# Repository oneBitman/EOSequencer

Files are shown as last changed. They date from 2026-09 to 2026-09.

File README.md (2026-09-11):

# EOSequencer

**EOSequencer** is an open-source hardware MIDI step sequencer firmware for Arduino and compatible microcontrollers. It is built as an enhanced fork of the classic **Beat707NXT** engine by William Kalfelz, featuring updated workflow options, refined timing stability, and customized interface controls.

🌐 **Website (buy a kit):** [https://dsmcz.com/prestashop/en/home/23957-eoseq-full-kit-with-eu-psu-yellow-purple-enclousure-v10-may-2026.html](https://dsmcz.com/prestashop/en/home/23957-eoseq-full-kit-with-eu-psu-yellow-purple-enclousure-v10-may-2026.html)

---

## Features

- **Multi-track Step Sequencing:** Intuitive step entry for rhythm and melodic tracks.
- **Hardware Integration:** Direct support for MIDI In/Out, TM1638 led & key board based interface.
- **Enhanced Engine:** Modifications built over Beat707NXT for improved stability and workflow options.
- **Arduino Compatible:** Designed to compile cleanly using the standard Arduino IDE.

---

## Hardware Requirements

To build and run EOSequencer, you will need:

1. **Microcontroller Board:**
   - Only for Arduino Pro Mini 328P, 3.3V, 8Mhz
   - Eosequencer was developed for ATmega328P but code will run flawless on 328PB variant
2. **User Interface Components:**
   - 3x TM1638 board
3. **MIDI Hardware Interface:**
   - Standard DIN-5 or TRS MIDI input and output circuits (optocoupler-driven MIDI IN, standard MIDI OUT driver).

---

## Software & Build Setup

### Option A: Using Arduino IDE

1. **Download & Install Arduino IDE** (v1.8.x or v2.x).
2. **Clone the Repository:**
   ```bash
   git clone https://github.com/oneBitman/EOSequencer.git
   ```
3. **Install Required Libraries:**
   Ensure the following libraries are installed in your Arduino library manager:
   - `MIDI` (by Francois Best)
   - `Wire` & `SPI` (Built-in)
4. **Open Project:**
   Open `EOSequencer.ino` inside the `EOSequencer/` folder.
5. **Compile & Upload:**
   You MUST install MiniCore board library for gaining more programming space, code exceeds 30720 bytes!
   Recommended bootloader (512 bytes): Optiboot/Urboot --- urboot_m328p_1s_autobaud_uart0_rxd0_txd1_led+b5_ee_ce_hw_stk500

   How to install MiniCore board library (Arduino IDE 2.x on Windows 11)

   File → Preferences → Additional Boards Manager URLs
   1.) → paste: https://mcudude.github.io/MiniCore/package_MCUdude_MiniCore_index.json
   2.) Tools → Board → Boards Manager… → search MiniCore → Install.
   Choose Tools > Board > MiniCore > Atmega328
    Select your target board and port under **Tools**, then click **Upload**.

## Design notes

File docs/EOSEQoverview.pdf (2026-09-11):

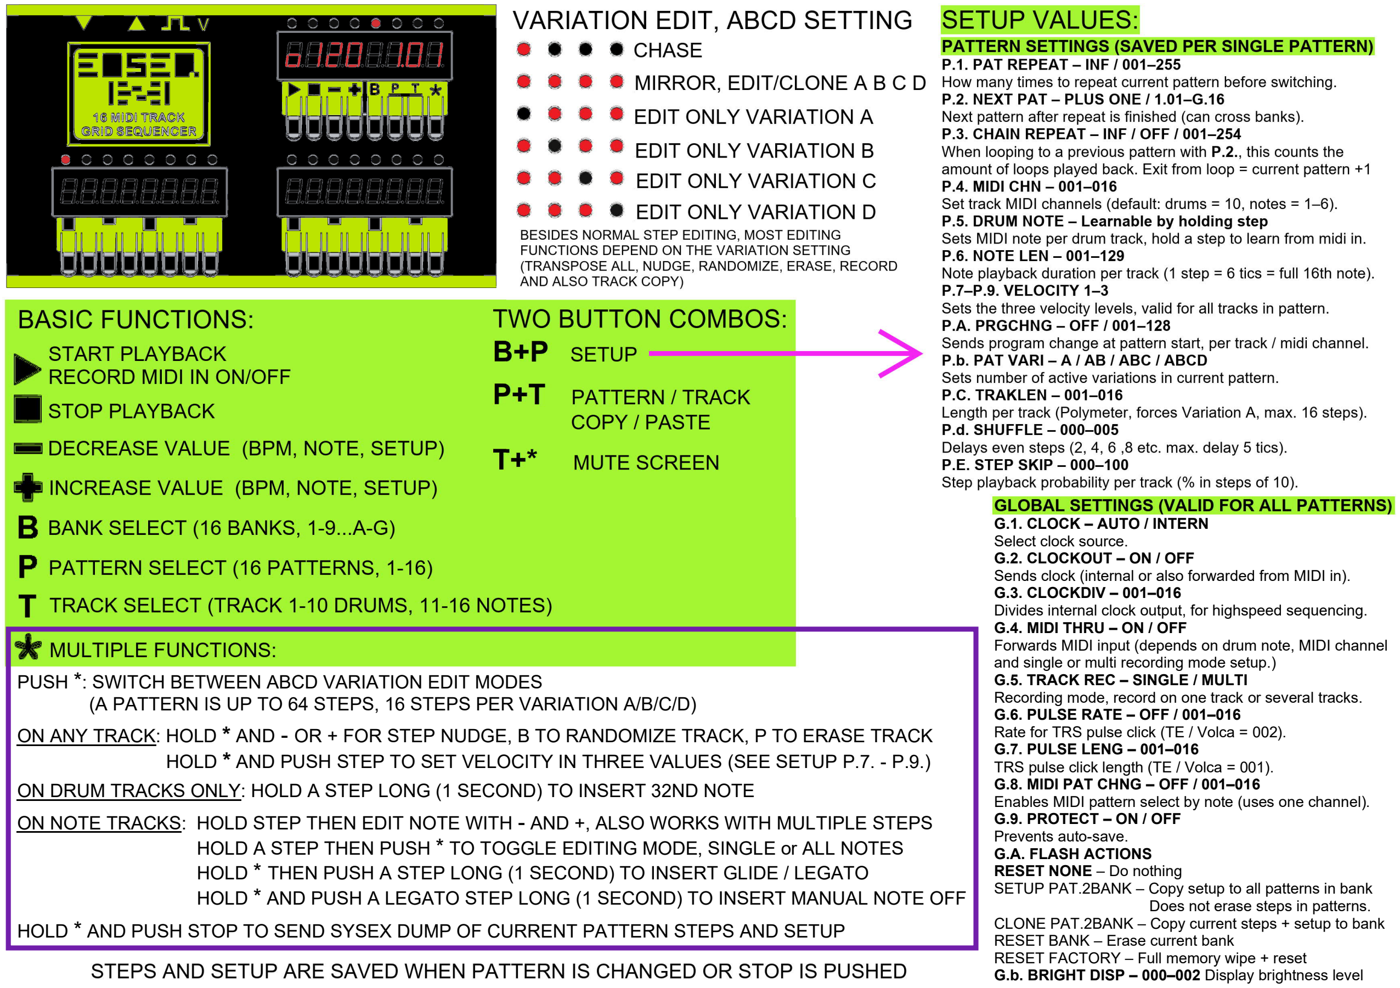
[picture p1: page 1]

PUSH *: SWITCH BETWEEN ABCD VARIATION EDIT MODES (A PATTERN IS UP TO 64 STEPS, 16 STEPS PER VARIATION A/B/C/D) ON ANY TRACK: HOLD * AND - OR + FOR STEP NUDGE, B TO RANDOMIZE TRACK, P TO ERASE TRACK HOLD * AND PUSH STEP TO SET VELOCITY IN THREE VALUES (SEE SETUP P.7. - P.9.) ON DRUM TRACKS ONLY: HOLD A STEP LONG (1 SECOND) TO INSERT 32ND NOTE ON NOTE TRACKS: HOLD STEP THEN EDIT NOTE WITH - AND +, ALSO WORKS WITH MULTIPLE STEPS HOLD A STEP THEN PUSH * TO TOGGLE EDITING MODE, SINGLE or ALL NOTES HOLD * THEN PUSH A STEP LONG (1 SECOND) TO INSERT GLIDE / LEGATO HOLD * AND PUSH A LEGATO STEP LONG (1 SECOND) TO INSERT MANUAL NOTE OFF HOLD * AND PUSH STOP TO SEND SYSEX DUMP OF CURRENT PATTERN STEPS AND SETUP

# TWO BUTTON COMBOS:

## B+P SETUP

## P+T PATTERN / TRACK COPY / PASTE T+* MUTE SCREEN

GLOBAL SETTINGS (VALID FOR ALL PATTERNS) G.1. CLOCK – AUTO / INTERN
Select clock source.
G.2. CLOCKOUT – ON / OFF
Sends clock (internal or also forwarded from MIDI in). G.3. CLOCKDIV – 001–016
Divides internal clock output, for highspeed sequencing. G.4. MIDI THRU – ON / OFF
Forwards MIDI input (depends on drum note, MIDI channel and single or multi recording mode setup.)
G.5. TRACK REC – SINGLE / MULTI
Recording mode, record on one track or several tracks. G.6. PULSE RATE – OFF / 001–016
Rate for TRS pulse click (TE / Volca = 002).
G.7. PULSE LENG – 001–016
TRS pulse click length (TE / Volca = 001).
G.8. MIDI PAT CHNG – OFF / 001–016
Enables MIDI pattern select by note (uses one channel). G.9. PROTECT – ON / OFF
Prevents auto-save.
G.A. FLASH ACTIONS
RESET NONE – Do nothing
SETUP PAT.2BANK – Copy setup to all patterns in bank Does not erase steps in patterns. CLONE PAT.2BANK – Copy current steps + setup to bank RESET BANK – Erase current bank
RESET FACTORY – Full memory wipe + reset
G.b. BRIGHT DISP – 000–002 Display brightness level

# BASIC FUNCTIONS:

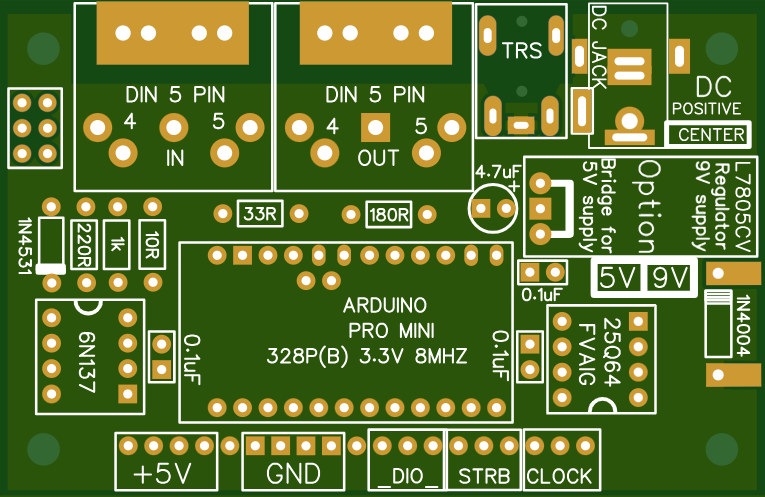
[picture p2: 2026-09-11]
hardware/gerber-export-1789131451506.png

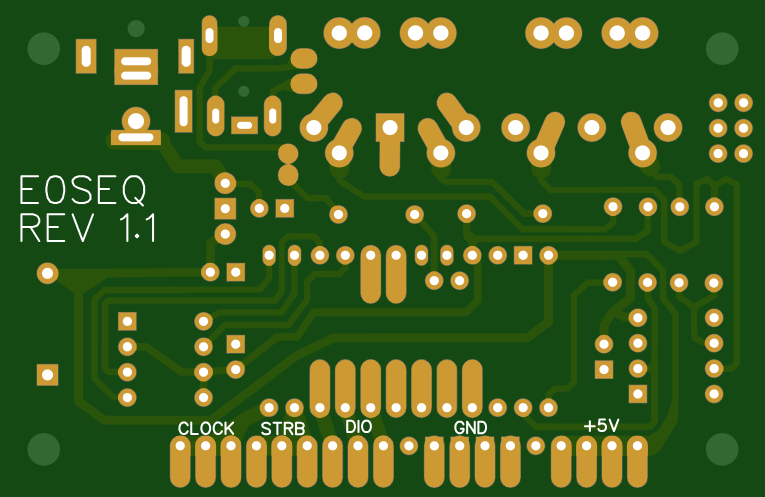
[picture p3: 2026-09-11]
hardware/gerber-export-1789131424221.png

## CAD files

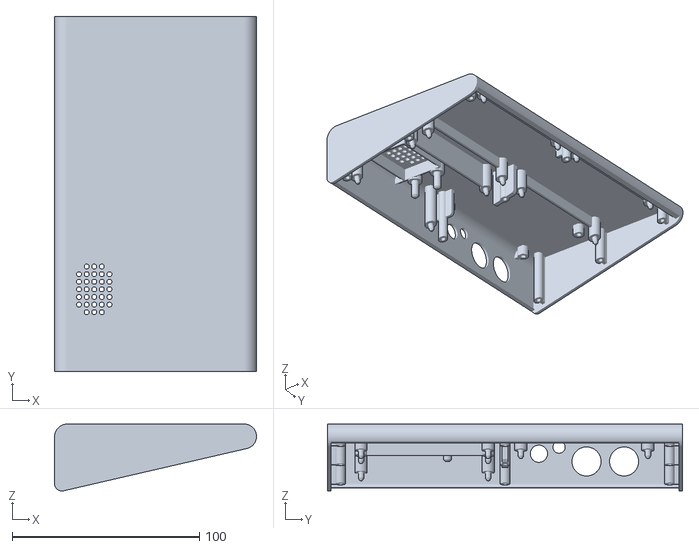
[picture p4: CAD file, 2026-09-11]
hardware/enclosure/wp5_Base.STL
108.0 x 189.7 x 35.8

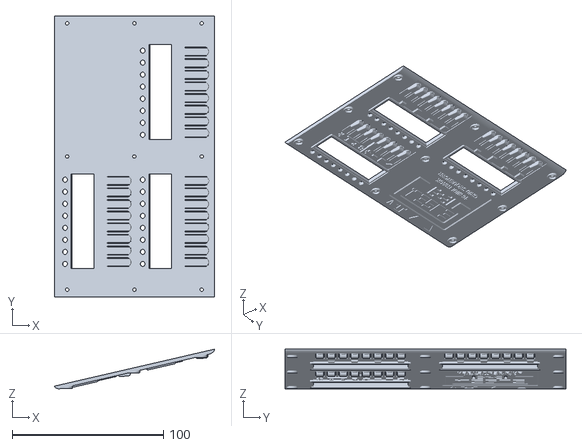
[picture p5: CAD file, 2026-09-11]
hardware/enclosure/wp6_Top.STL
106.0 x 185.7 x 26.2

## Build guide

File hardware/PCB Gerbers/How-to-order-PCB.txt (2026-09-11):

How to Order PCB

Please refer to:
https://docs.easyeda.com/en/PCB/Order-PCB

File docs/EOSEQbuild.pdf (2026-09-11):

# *** EOSEQUENCER ***

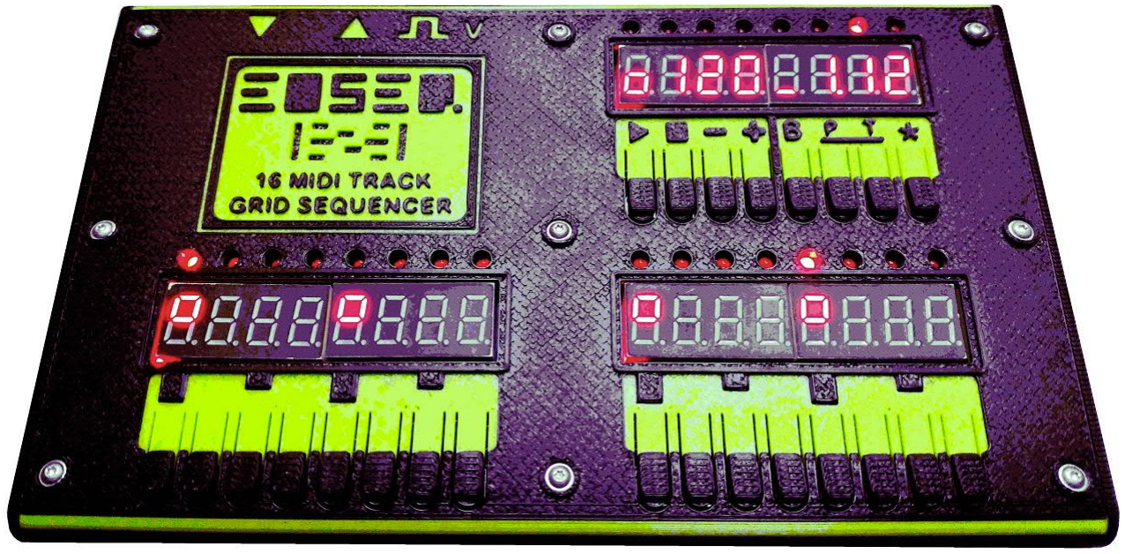
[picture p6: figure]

# DIY BUILD MANUAL PCB VERSION 1 . 1

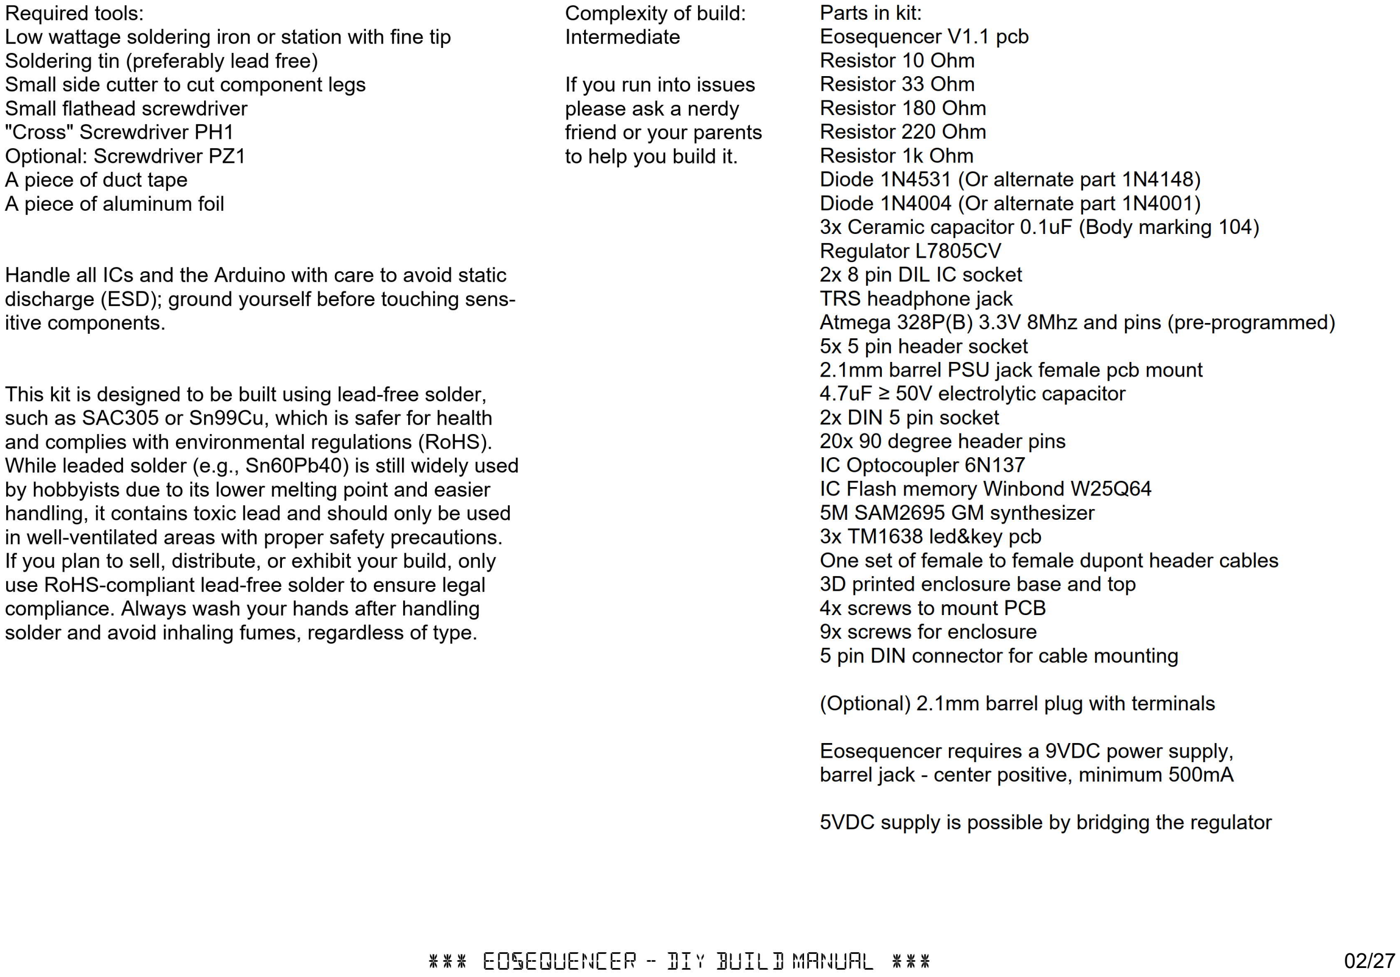
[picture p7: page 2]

Parts in kit:
Eosequencer V1.1 pcb
Resistor 10 Ohm
Resistor 33 Ohm
Resistor 180 Ohm
Resistor 220 Ohm
Resistor 1k Ohm
Diode 1N4531 (Or alternate part 1N4148) Diode 1N4004 (Or alternate part 1N4001)
3x Ceramic capacitor 0.1uF (Body marking 104) Regulator L7805CV
2x 8 pin DIL IC socket
TRS headphone jack
Atmega 328P(B) 3.3V 8Mhz and pins (pre-programmed) 5x 5 pin header socket
2.1mm barrel PSU jack female pcb mount
4.7uF 50V electrolytic capacitor
2x DIN 5 pin socket
20x 90 degree header pins
IC Optocoupler 6N137
IC Flash memory Winbond W25Q64
5M SAM2695 GM synthesizer
3x TM1638 led&key pcb
One set of female to female dupont header cables 3D printed enclosure base and top
4x screws to mount PCB
9x screws for enclosure
5 pin DIN connector for cable mounting

(Optional) 2.1mm barrel plug with terminals

Eosequencer requires a 9VDC power supply, barrel jack - center positive, minimum 500mA

5VDC supply is possible by bridging the regulator

Find resistor 10 Ohm
Brown Black Black Gold
Bend legs | Put resistor in place
Solder in place | Trim legs

Find resistor 33 Ohm
Orange Orange Black Gold
Bend legs | Put resistor in place
Solder in place | Trim legs

Find resistor 180 Ohm
Brown Gray Brown Gold
Bend legs | Put resistor in place
Solder in place | Trim legs

Find resistor 220 Ohm
Red Red Brown Gold
Bend legs | Put resistor in place
Solder in place | Trim legs

Find resistor 1k Ohm
Brown Black Red Gold
Bend legs | Put resistor in place
Solder in place | Trim legs

Find diode 1N4531
Red body colour
Alternate part: 1N4148
Bend legs | Put diode in place, observe correct orientation as indicated on pcb
Solder in place | Trim legs

Find diode 1N4004
Black body colour
Alternate part: 1N4001
Bend legs | Put diode in place, observe correct orientation as indicated on pcb
Solder in place | Trim legs

Find 3x capacitor 0.1uF
Body marking 104
Put capacitors into place | Solder in place

Trim legs

Find voltage regulator L7805CV Bend legs as shown

Put regulator into place
Regulator should be mounted with distance from pcb, it can slightly heat up and we do not want heat to spread to other components

Solder regulator pins

Alternative version for 5VDC supply: Instead of regulator solder a bridge in place (Use leftovers from component legs)

Solder bridge in place

Find 2x 8 pin IC sockets | Put sockets into place, mind orientation notch as in- dicated on pcb

Optionally bend two pins of each socket so they don't fall out

Solder both sockets into place | Finished socket left | Finished socket right

Find TRS headphone jack | Put headphone jack into place | Solder headphone jack in place

Finished headphone socket

Find arduino and pins in bag | Divide pins as shown, keep 90° pins in bag for later | Put pins into pcb as shown, short end on top, mind the gap - We are using pcb as a holder to mount the pins to arduino.
Put arduino onto pins | Solder all pins, only on arduino, not on bottom of pcb | Finished arduino with pins, remove arduino from pcb

Find 5x 5pin header sockets | Mount 4x 5pin header sockets as shown | Cut the remaining header socket in the middle to cre- ate a 2pin header socket. If you don't have a proper side cutter, cut the plastic on both sides with a knife and break it apart.
Mount 2pin header socket to arduino | Place arduino with header sockets into pcb | Solder all header socket pins

Find remaining 90° pins from arduino bag | Put pins into place | Solder pins in place
Finished 90° pins | Bend capacitor under pins towards pcb, slightly bend 90° pins upwards not to conflict with later mounted IC

Find PSU socket | Put PSU socket into place | Solder socket in place Alternate part might have different pins

Finished PSU socket

Find capacitor 4.7uF 50V | Put capacitor into place, mind orientation: Line on cap further away from regulator
Put capacitor into place,
orientation check: Shorter leg of cap is further away from regulator
Solder cap in place | Trim legs

Find 2x DIN 5 pin socker | Put sockets into place | Solder sockets in place
Finished DIN sockets | Optional for more stability: Solder grounding tab to pcb

Finished stability improvement

Find 19x 90° pins | Put 90° pins into place | Solder 90° pins in place

Optional: Header wiring can be soldered directly to pcb bottom without any pins

Find IC's 6N137 and W25Q64
Mount IC's into sockets, mind orientation 6N137 might have a dot instead a notch, dot = notch side

Bend arduino 90° pins if not done yet, mount arduino Pcb fully assembled

Find M5 SAM2695 midi synthesizer, cut off header cable approximately in half

Cut off the white wire, strip and tin the yellow, red and black wire ends

Put M5 SAM2695 into place on plastic pins | Optional: Melt down the pins to mount M5 SAM2695 Hint: Use a piece of aluminum foil for melting down to keep the soldering tip clean If pins are not melt down the M5 SAM2695 might slightly rattle inside the enclosure when moved M5 SAM2695 mounting done
Solder yellow wire to shown pin on midi out | Solder red and black wire to pads at black diode | Route wires as shown M5 SAM2695 installation done

Find 4x B3X6 screws and mount circuit board with PH1 screwdriver (No need to use PZ1 screwdriver)

Find 3x TM1638 led&key board
Use a flat screwdriver or flat knife to remove plastic from TM1638 led&key board

Plastic removed

Find female to female header wires
Tear off three sections with 5x identical colours
Plug header cables to TM1638 board | Bend the pins downwards Do this for all three boards Remove the header wires after bending

Due to chinese production quality fluctuations it can be that buttons or leds are not perfectly flat Eosequencer tongue principle requires tactiles to be aligned properly with pcb

Heat up pins and add some soldering tin if a tactile or LED is not perfectly aligned, push the element into position

Plug wires to header pins as shown
Wires white, gray, blue, green are routed to all boards identical, only DIO wire (purple) goes individually to each board - Mind, pin between VCC and GND, between GND and DIO are not used

Route wires as shown, bend all header pins on Eosequencer PCB slightly downwards to have more space for installation when fitting led&key PCB

Attach wires to TM1638 board
Finished installation of main interface board

VCC GND DIO STB CLK

Plug wires for right step board, temporarily remove main interface board for routing wires

Prepare routed wires for right step board as shown Put wires for right step board aside, plug wires for left step board

Route wires for left step board as shown, eventually shorten pins of LEDs and segment displays on underside to avoid conflict with header pins

Place duct tape over connectors and wires to prevent accidential unplugging or shorts
Compress the wiring as much as possible to be able to install the left step board without conflict

Bend the pins and headers upwards to put the board into place

VCC GND DIO STB CLK

VCC GND DIO STB CLK

VCC GND DIO STB CLK

right step board main interface board

left step board

Left step board finished installation | Install right step board, route excess wire under the pcb. Bend pins and headers as shown, the installa- tion must be as flat as possible
Put main interface board back into place

Do a test run - On first power up Eosequencer is formatting the flash chip which takes a few seconds, do not interrupt the process - If the unit does not power on, check power supply polarity and doublecheck IC and Arduino pin seating, make sure regulator metal tab does not touch PSU jack or diode!

Optional for stability: Melt down all TM1638 mounting pins with aluminium foil, normally the three TM1638 pcb's will stay in their place when the top plate is mounted - Make sure all header wires have proper contact before melting down the pins

Find 9x B2.5X10 screw, mount top plate with PH1 screwdriver
Push top plate into place centered before tightening the first screw

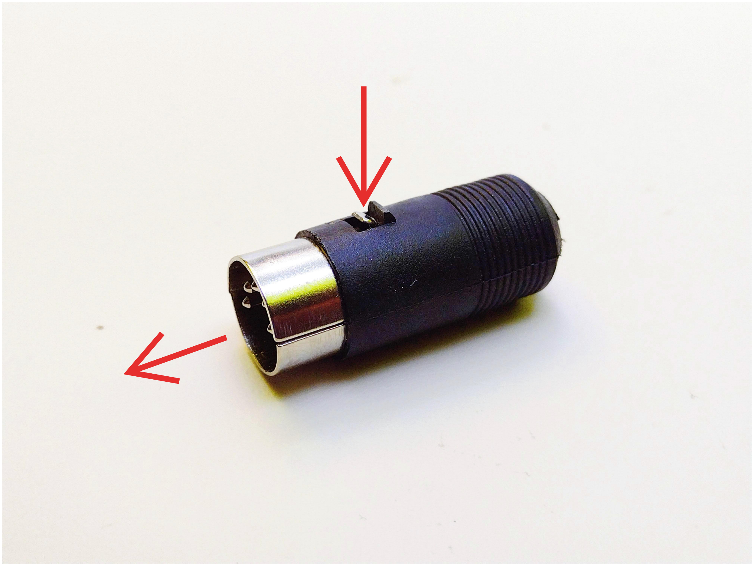
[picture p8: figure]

Internal soundcard Midi Out loopback adapter
Find 5 PIN DIN connector, push connector nose and disassemble

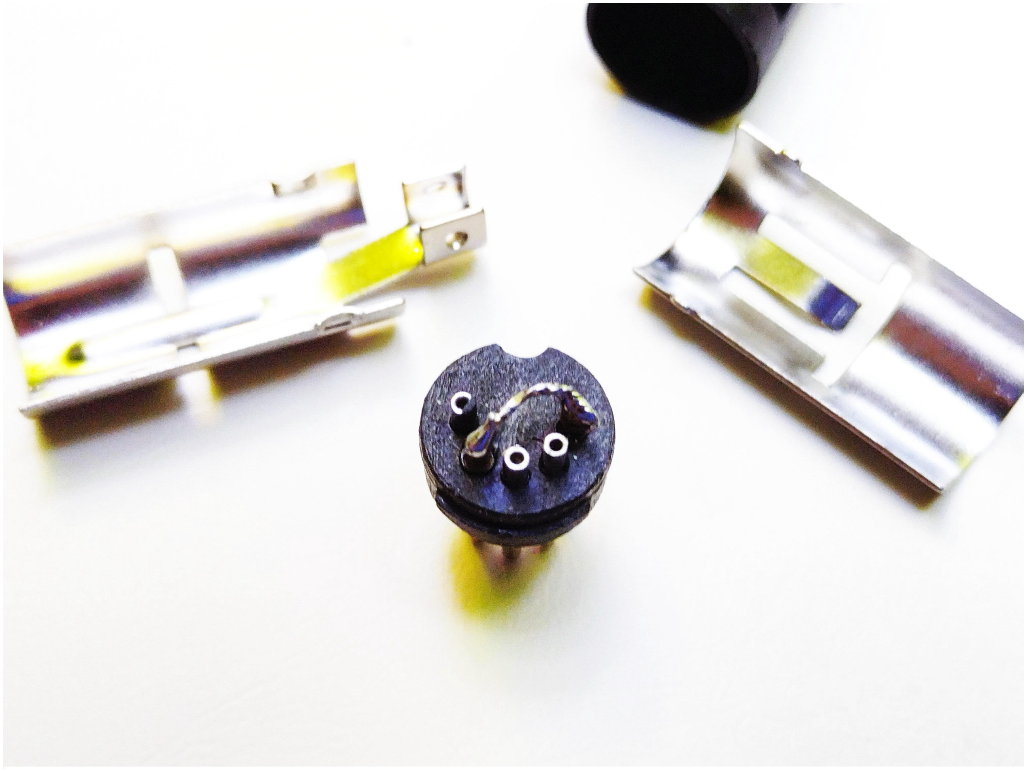
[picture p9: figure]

Use a clipped off component leg or piece of wire to install the bridge as shown
This routes midi output from Eosequencer back to midi input of the M5 SAM2695 synth, using a pin that is commonly unused for midi connections

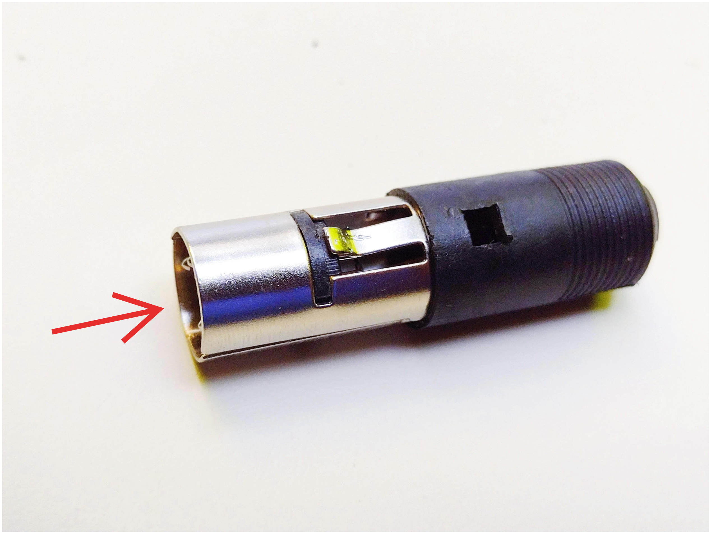
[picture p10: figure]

Reassemble the connector, push connector nose upwards again if needed

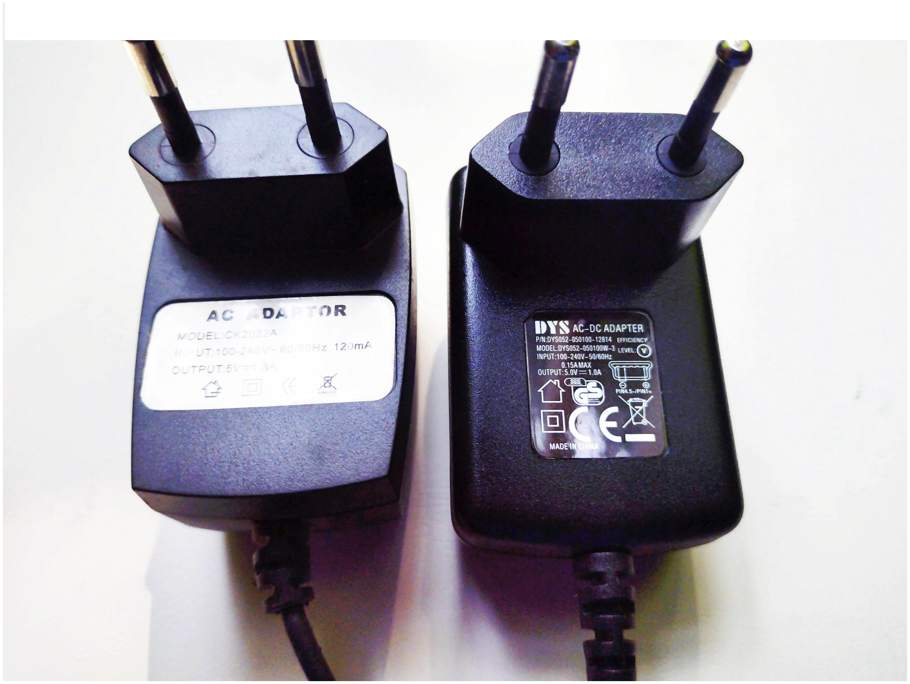
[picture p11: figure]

The 5V power variant can be powered by any old phone charger that delivers atleast 400mA. Also using USB cables or powerbanks is possible
Do not power the 9V variant from 5V - it may behave erratically

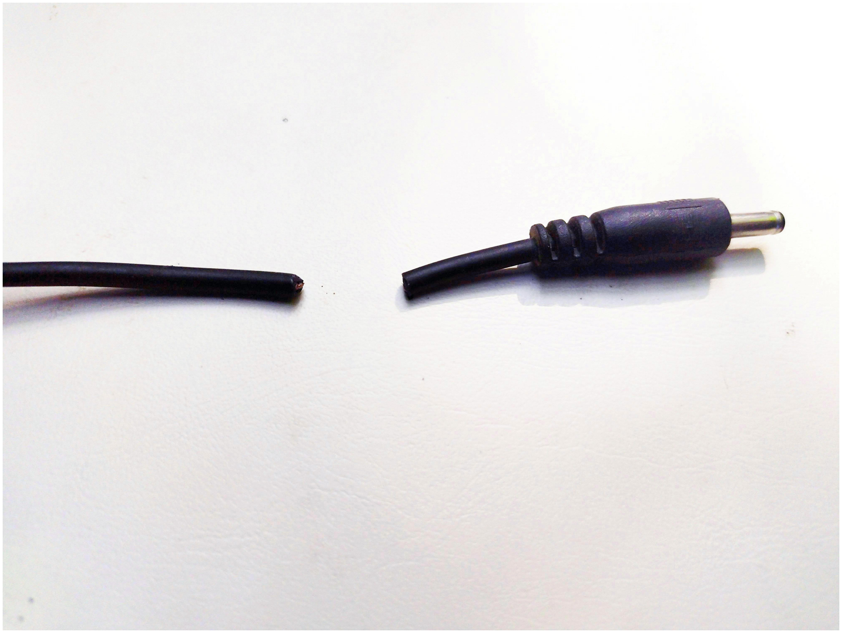
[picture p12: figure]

Remove original charger connector and connect it to provided barrel plug wit terminals

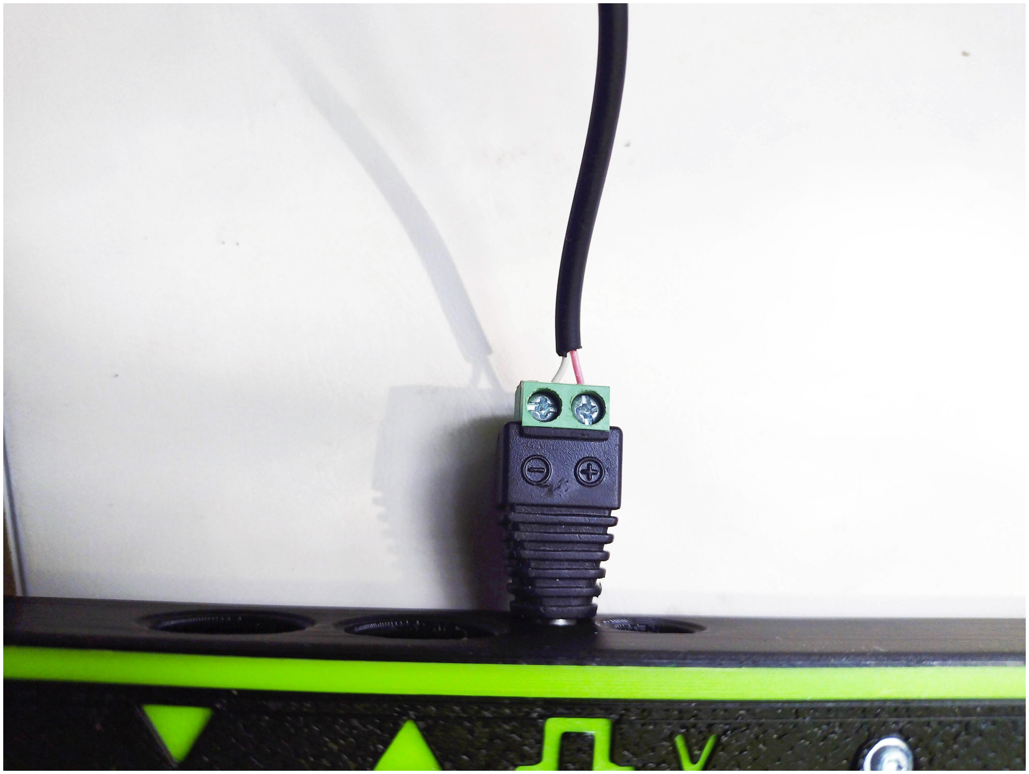
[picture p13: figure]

Since the pcb has a polarity protection diode, just attach the wires and check if it powers up. If not, swap the wire
On a USB power / data cable use only the red and black wires, insulate other wires (white, green etc.)

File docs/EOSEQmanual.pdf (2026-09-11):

# *** EOSEQUENCER ***


# QUICK START MANUAL SOFTWARE VERSION 2 . 0

## CONTENT

Introduction | 03
Main screen and interface | 04
Bank, Pattern and Track selection | 05
A B C D Variation, Velocity editing, Drum step editing, Track activity indicators.......06
Nudge steps, randomize and erase | 07
Note track editing, transpose | 08
Single and multitrack recording, Note input indicators | 09
Mute screen | 10
Pattern copy | 11
Track copy | 12
Setup menu | 13
Memory slot selection, Flash memory endurance, Memory map | 14
Pattern setup parameters | 15
Global setup parameters | 16
Frequently asked questions | 17, 18

Eosequencer is a minimalistic 16-track step sequencer built entirely around DIN MIDI. The segment display design draws inspiration from classic pinball machines. Featuring an internal GM synth it can be used as a portable sequencing device. Interface & Workflow
16-step grid-based sequencing with 16th note quantization
Classic LED chase playback, Segment LED display interface, Clicky tactile buttons Track Types
Each track has 3 velocity levels (editable per step)
Independent MIDI channel per track
Tracks 1–10: Drum tracks - Single note playback Optional 32nd step support (e.g. for flams / rolls) Tracks 11–16: Note tracks
Monophonic with legato / slide
Pattern Structure
Up to 64 steps per pattern, 64 steps = 4 variations per pattern (A, B, C, D) Mirror mode for editing all variations at once
16 banks × 16 patterns = 256 total patterns
7 Independent memory slots each containing 256 patterns
Note Input & Editing
Classic x0x-style step entry
Live MIDI input recording, Single-track or multi-track recording mode
Fast note editing: transpose, velocity, step nudging
Additional tools: randomization, chance-based playback
All important parameters (note, channel, note length, etc.) are saved per pattern Timing & Sync
External MIDI clock sync
Internal clock output (optionally divided down) or external clock forwarding
Internal clock tempo range: 1–999 BPM - High speed sequencing - increased resolution Click Sync Out for TE Pocket Operators / Korg Volca
Shuffle (Roger Linn style with half resolution 24 PPQN)
Advanced Performance Features
Per-track polymetrics: 1–16 steps per track looping independently Pattern chaining + performance mode
Program Change per track
Pattern change via incoming MIDI notes
Deep copy / paste functions for tracks, patterns, and parameter sets

## INTRODUCTION - * WHAT IS EOSEQUENCER? *

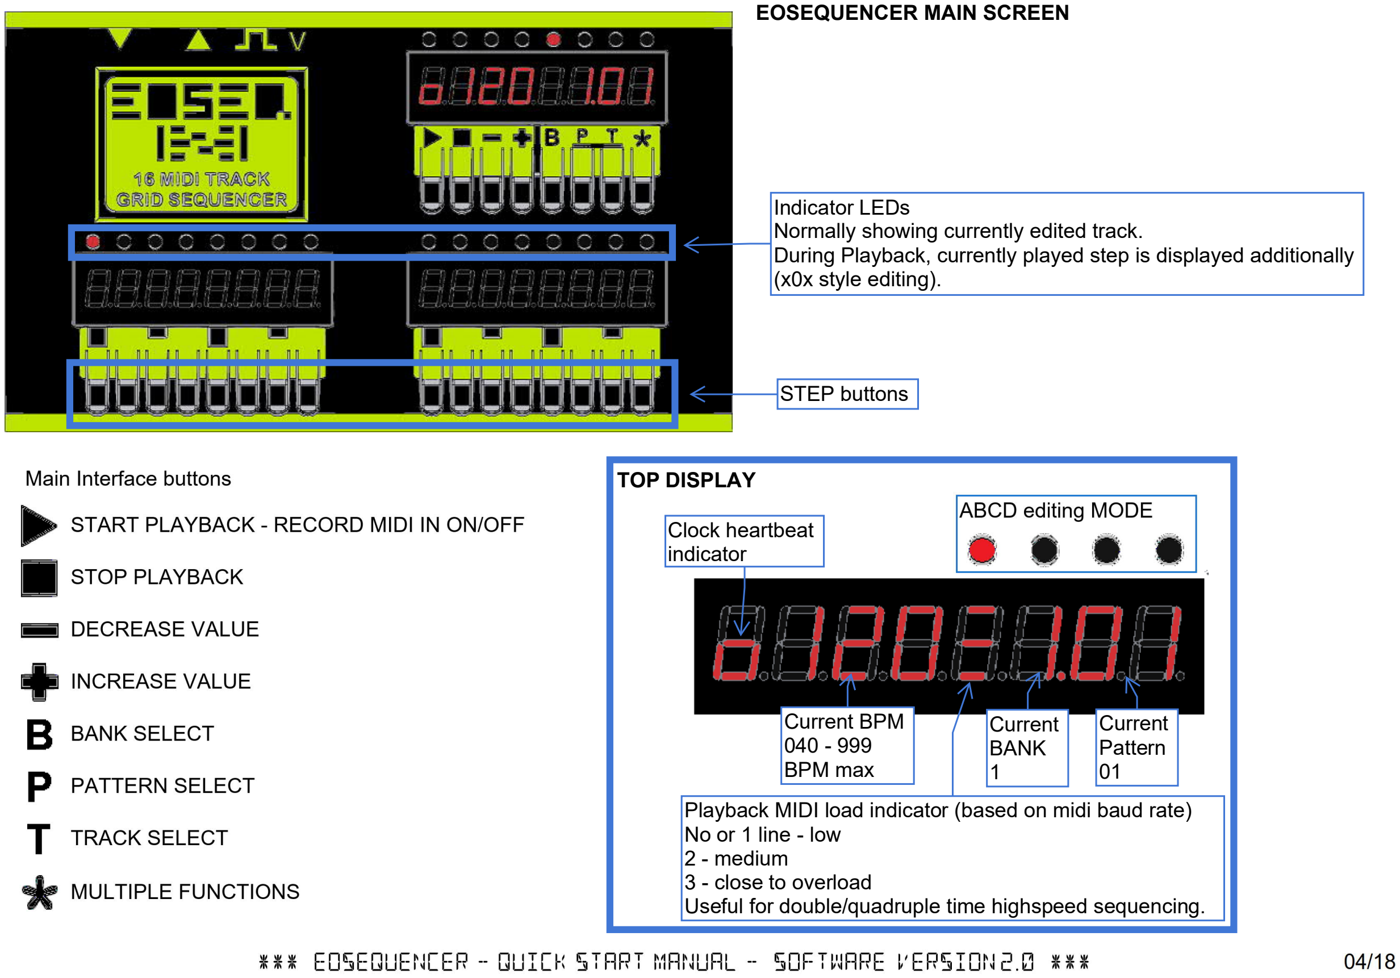
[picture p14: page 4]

TOP DISPLAY

Clock heartbeat
indicator

Current BPM
040 - 999
BPM max

Current
BANK
1

Current
Pattern
01

STEP buttons

Indicator LEDs
Normally showing currently edited track.
During Playback, currently played step is displayed additionally (x0x style editing).

EOSEQUENCER MAIN SCREEN

Playback MIDI load indicator (based on midi baud rate) No or 1 line - low
2 - medium
3 - close to overload
Useful for double/quadruple time highspeed sequencing.

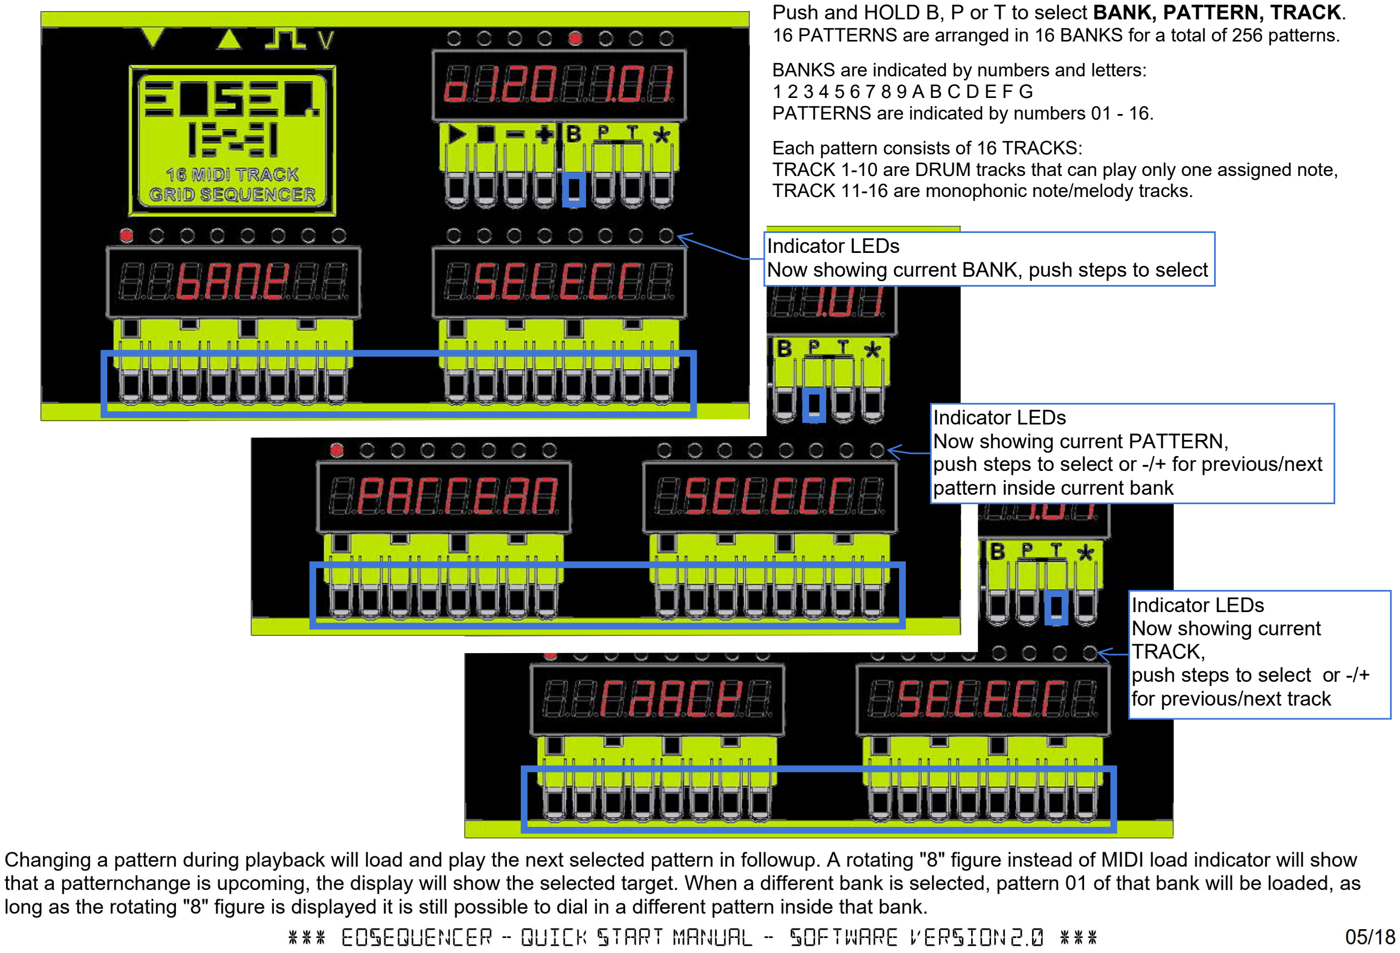
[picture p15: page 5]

Indicator LEDs
Now showing current
TRACK,
push steps to select or -/+ for previous/next track

Indicator LEDs
Now showing current BANK, push steps to select

Indicator LEDs
Now showing current PATTERN,
push steps to select or -/+ for previous/next pattern inside current bank

Push and HOLD B, P or T to select BANK, PATTERN, TRACK. 16 PATTERNS are arranged in 16 BANKS for a total of 256 patterns. BANKS are indicated by numbers and letters:
1 2 3 4 5 6 7 8 9 A B C D E F G
PATTERNS are indicated by numbers 01 - 16.
Each pattern consists of 16 TRACKS:
TRACK 1-10 are DRUM tracks that can play only one assigned note, TRACK 11-16 are monophonic note/melody tracks.

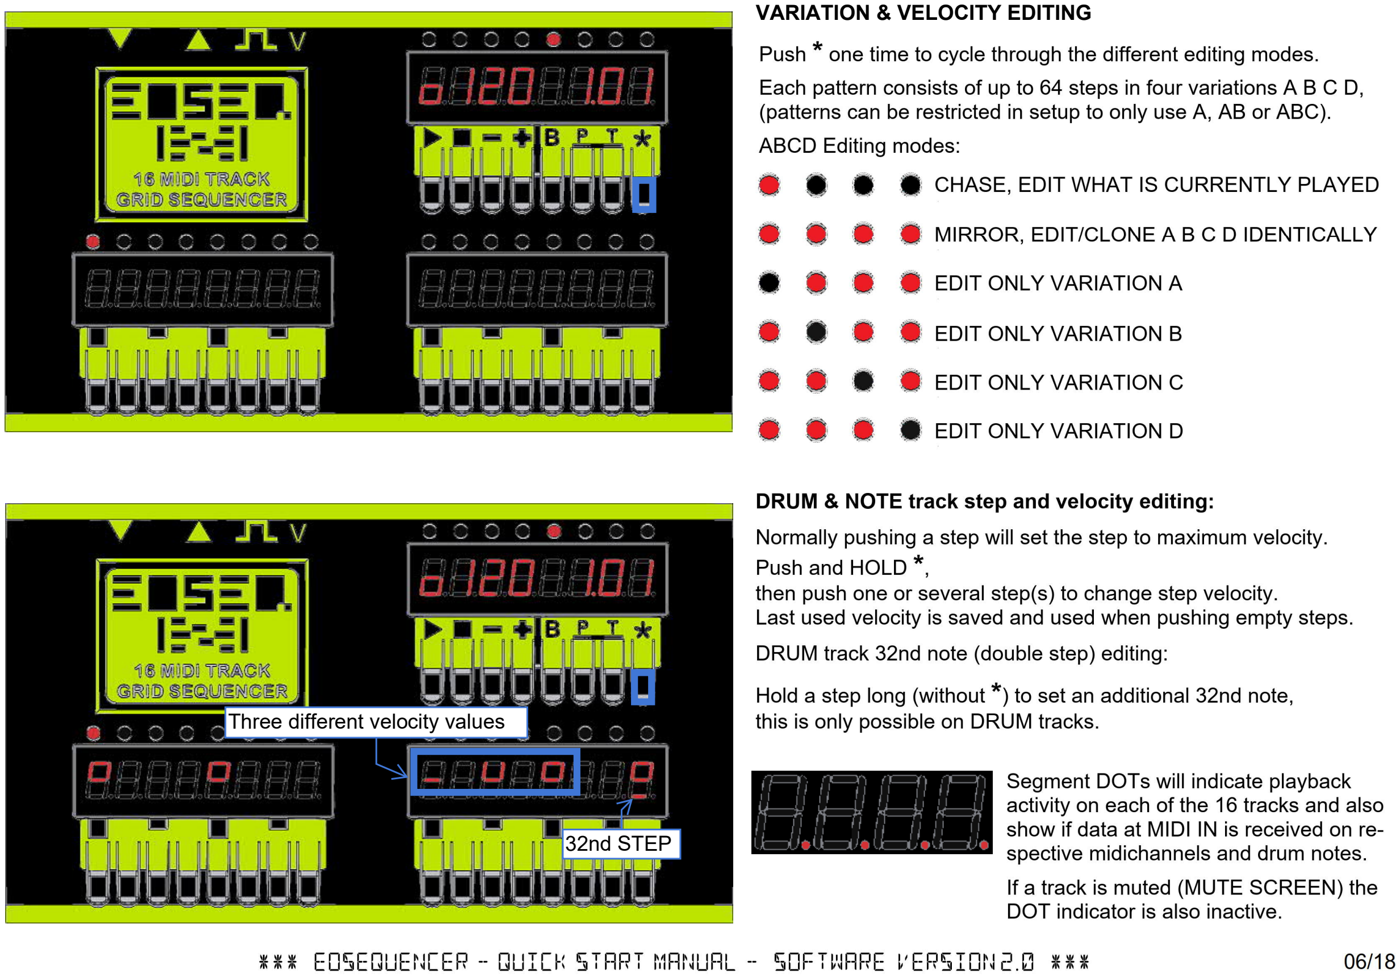
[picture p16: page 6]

32nd STEP

Three different velocity values

VARIATION & VELOCITY EDITING

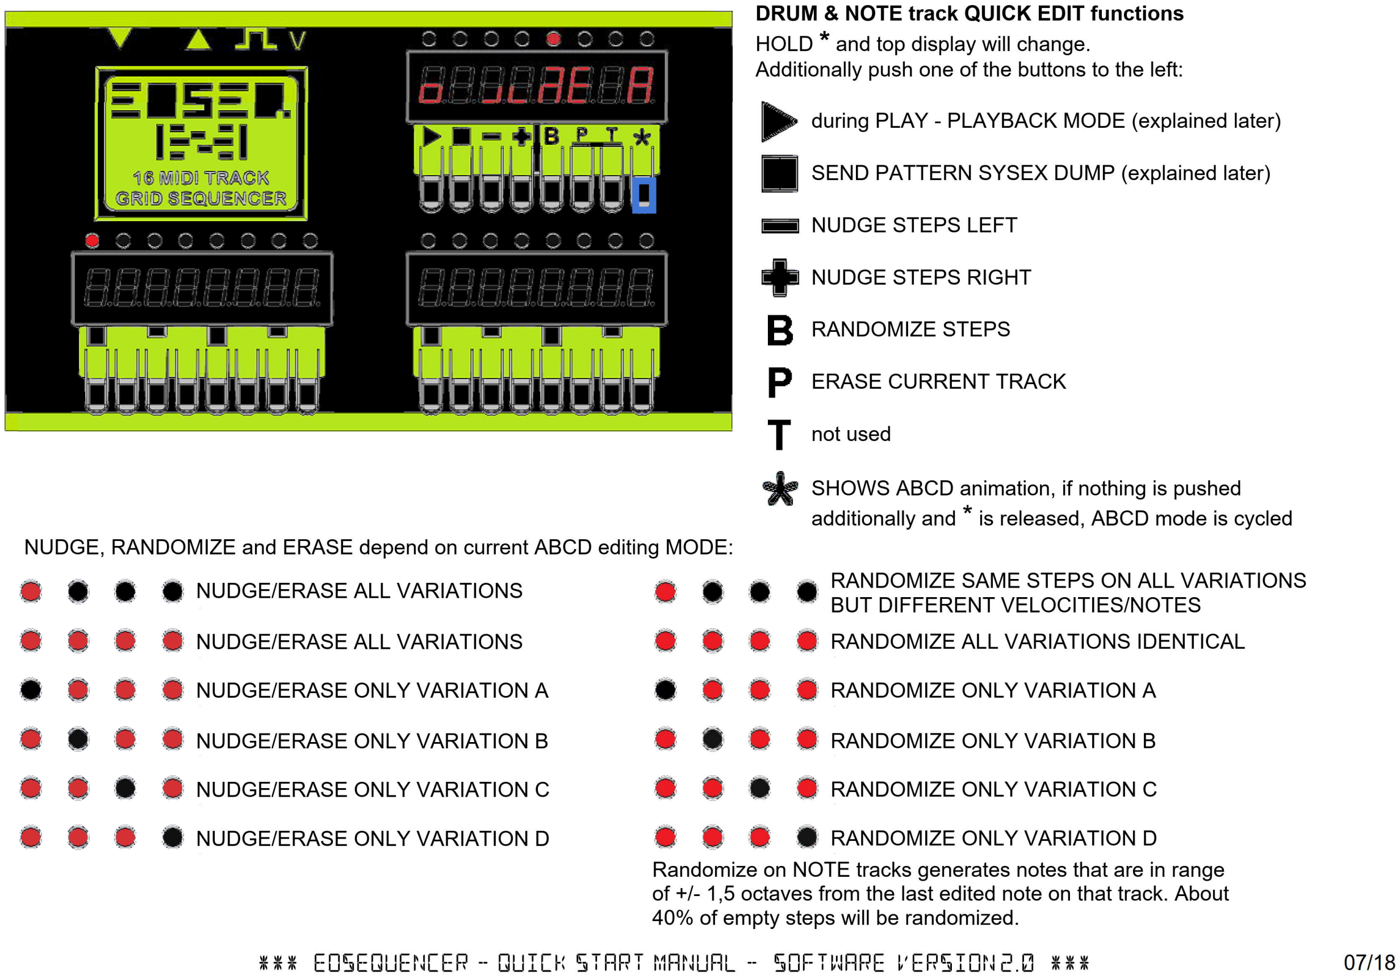
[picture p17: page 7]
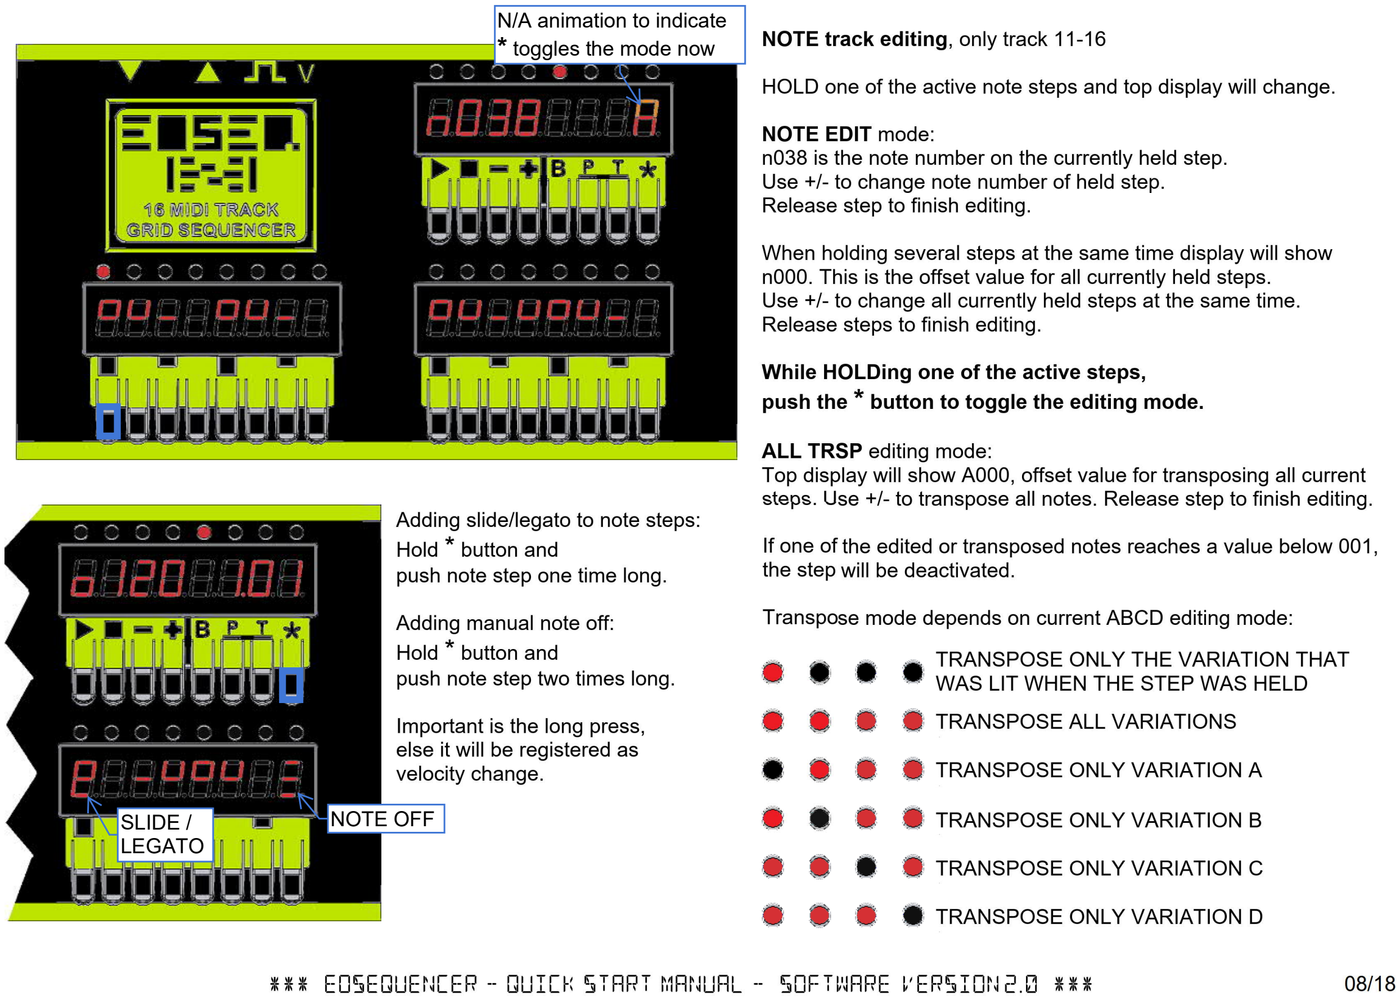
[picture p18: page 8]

SLIDE / | NOTE OFF
LEGATO

N/A animation to indicate
* toggles the mode now

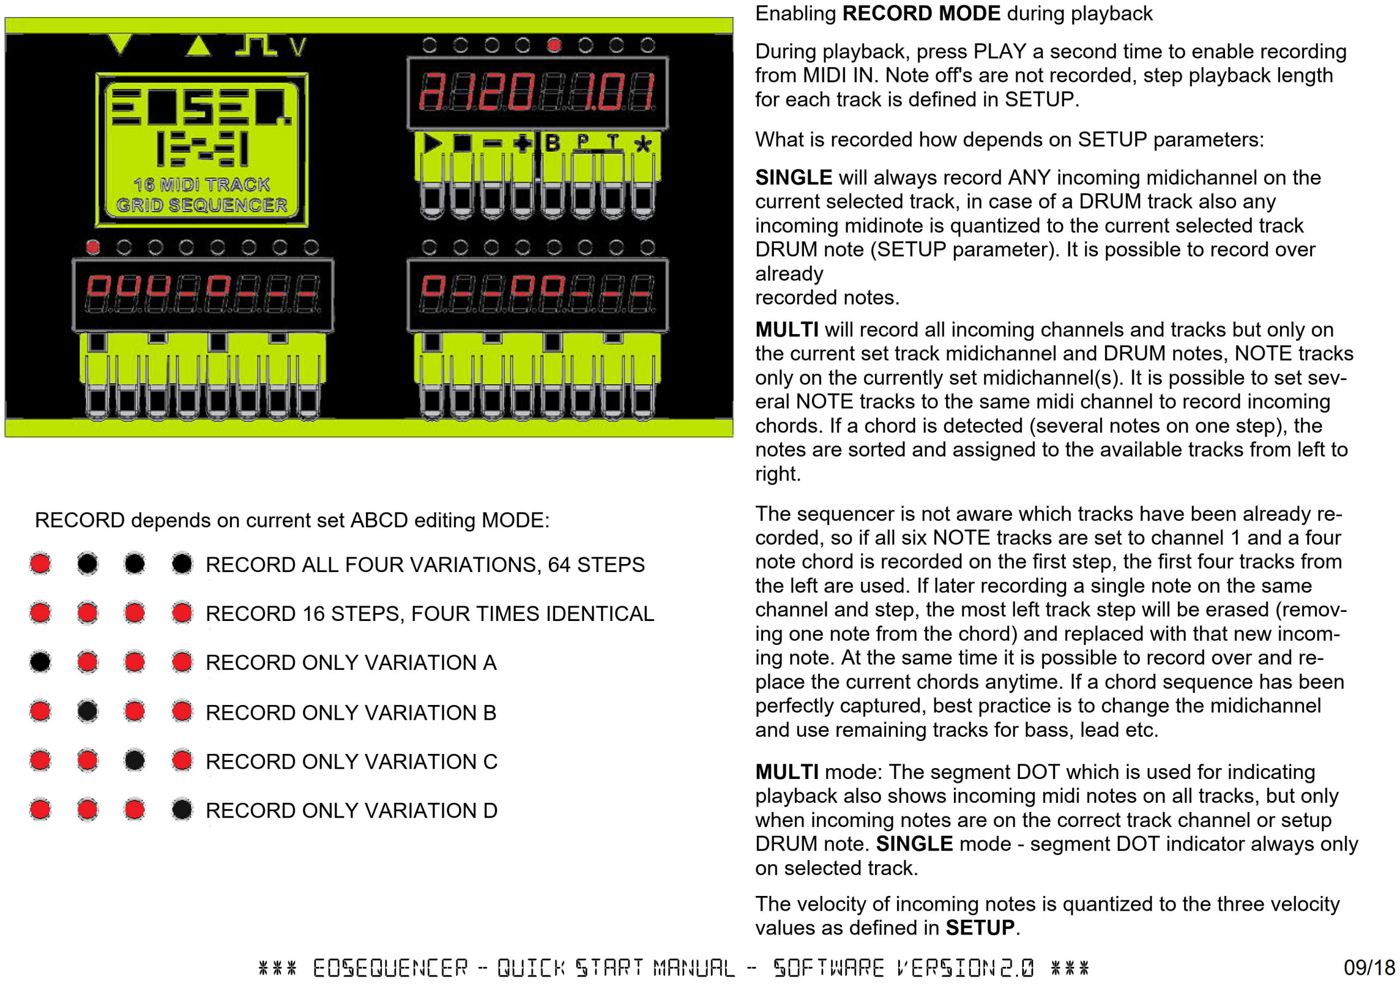
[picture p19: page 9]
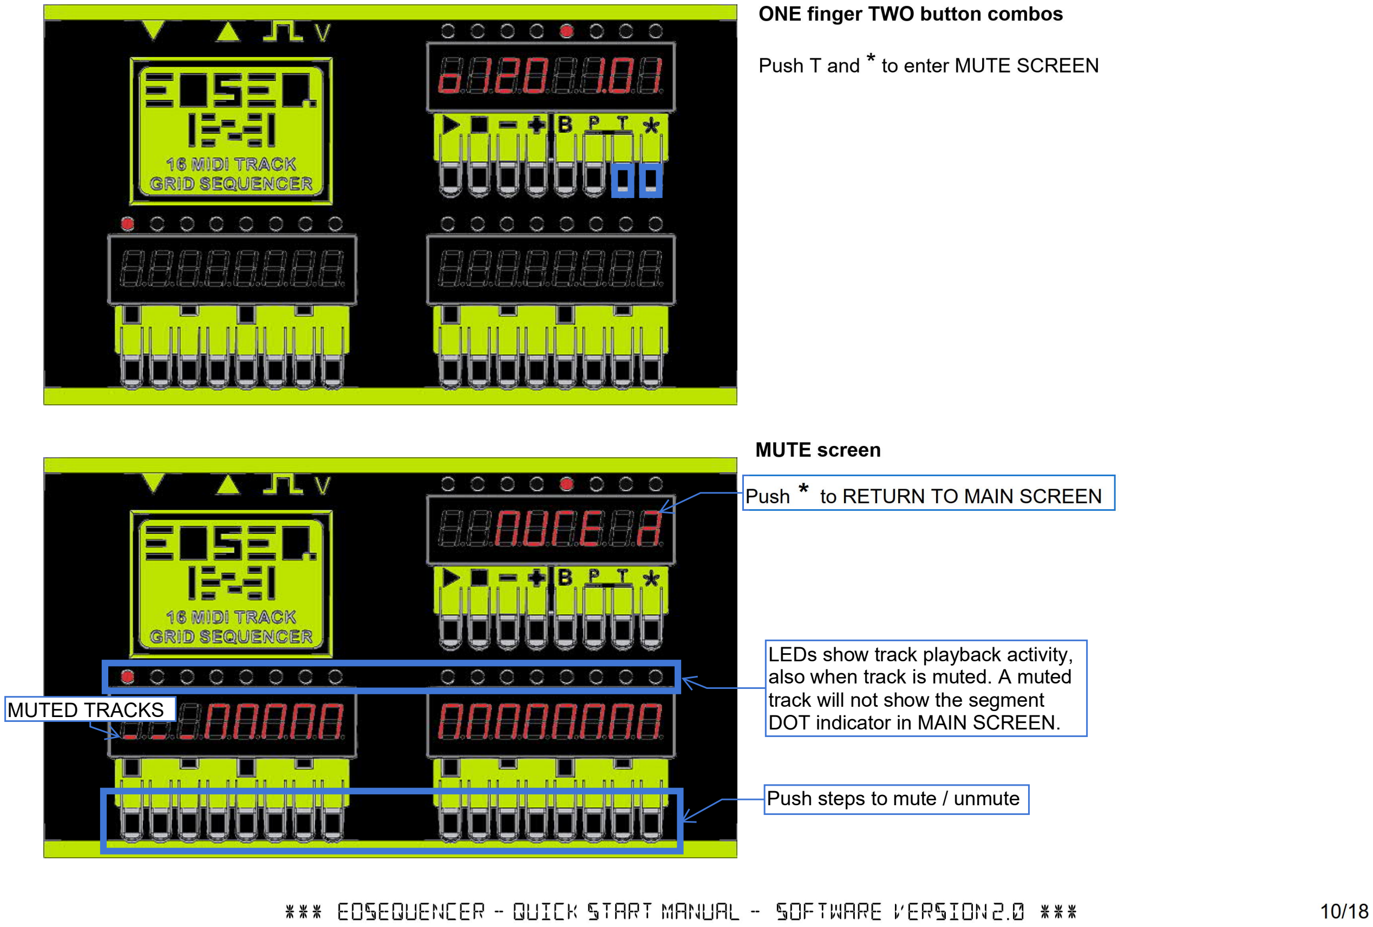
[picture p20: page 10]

LEDs show track playback activity, also when track is muted. A muted track will not show the segment DOT indicator in MAIN SCREEN.

Push steps to mute / unmute

Push * to RETURN TO MAIN SCREEN

MUTED TRACKS

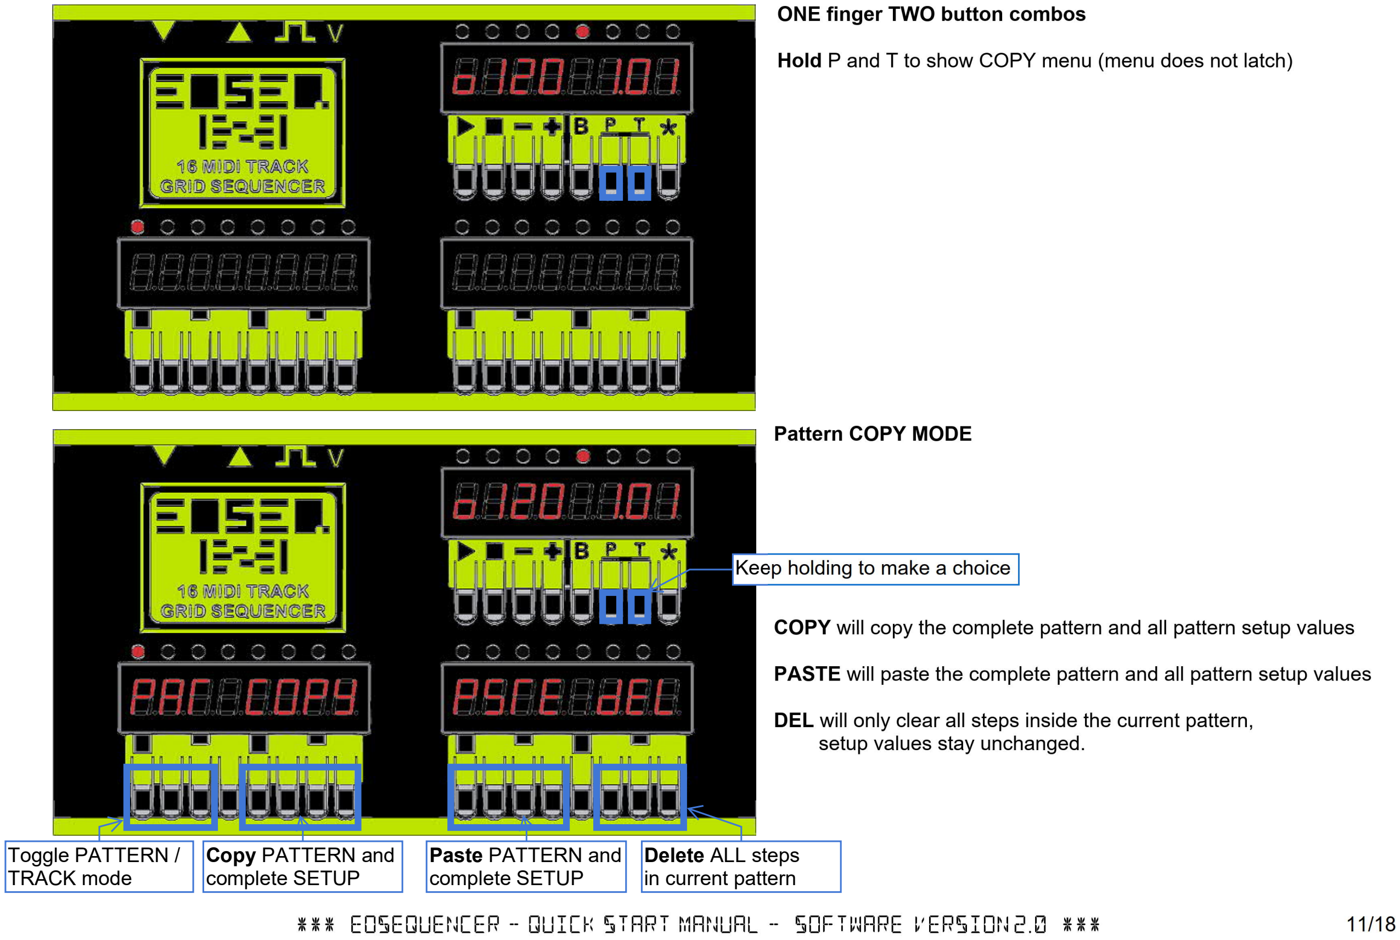
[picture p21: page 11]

Keep holding to make a choice

Toggle PATTERN /
TRACK mode

Copy PATTERN and
complete SETUP

Paste PATTERN and
complete SETUP

Delete ALL steps
in current pattern

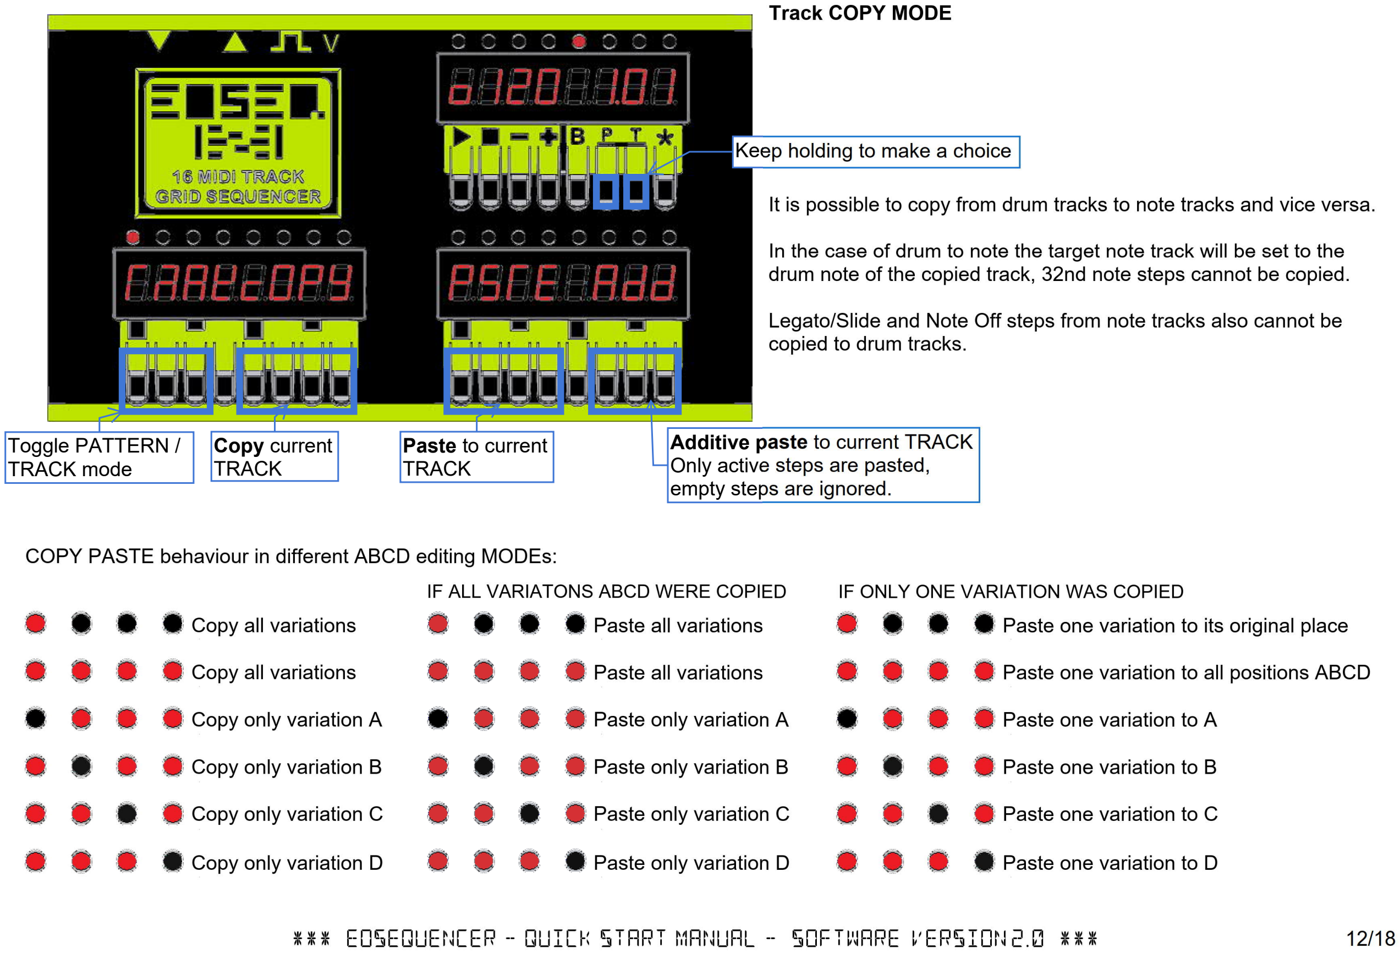
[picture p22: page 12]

Keep holding to make a choice

Toggle PATTERN /
TRACK mode

Copy current
TRACK

Paste to current
TRACK

Additive paste to current TRACK Only active steps are pasted, empty steps are ignored.

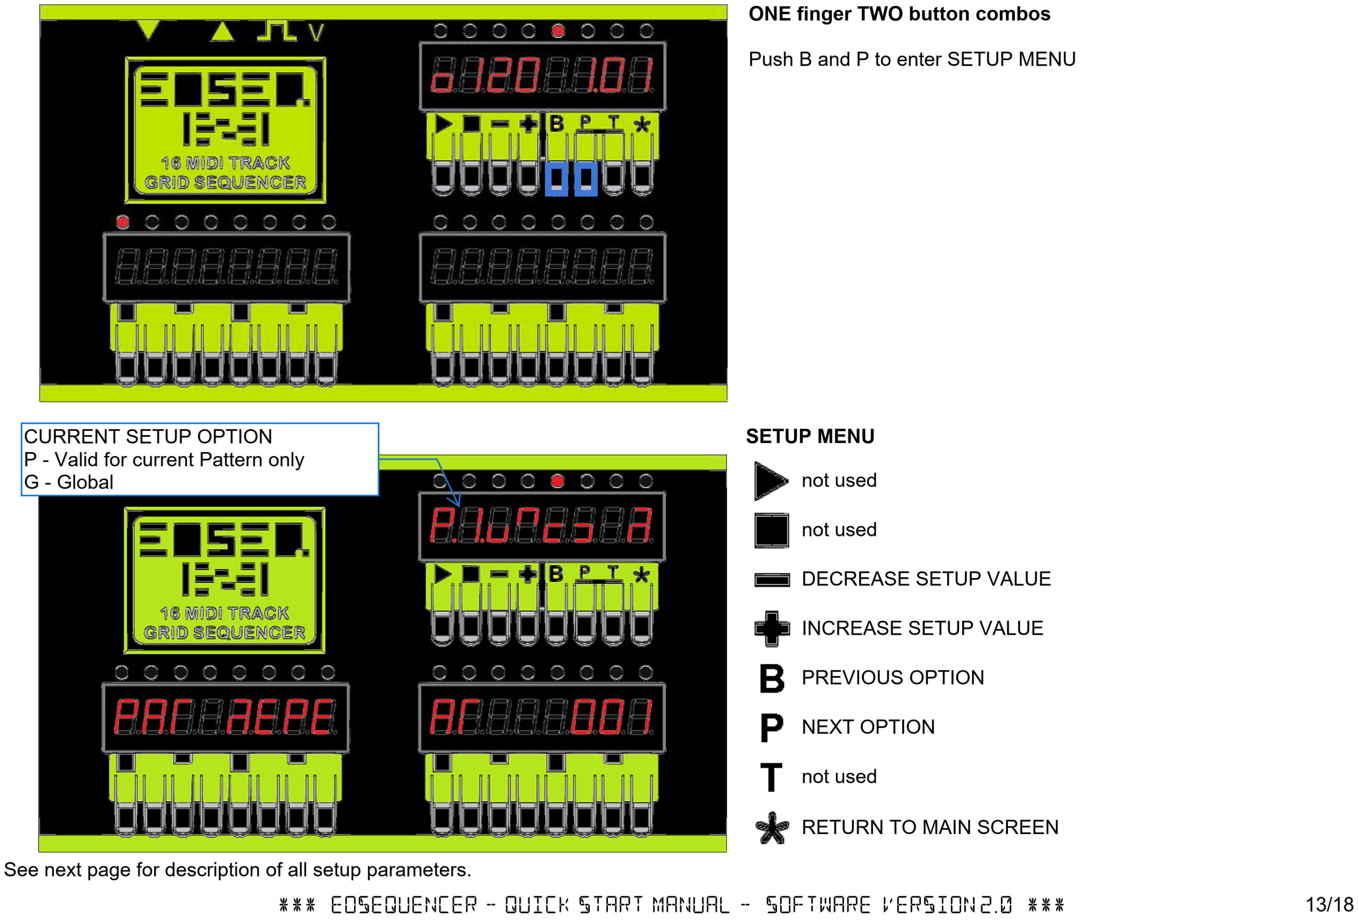
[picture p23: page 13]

CURRENT SETUP OPTION
P - Valid for current Pattern only G - Global

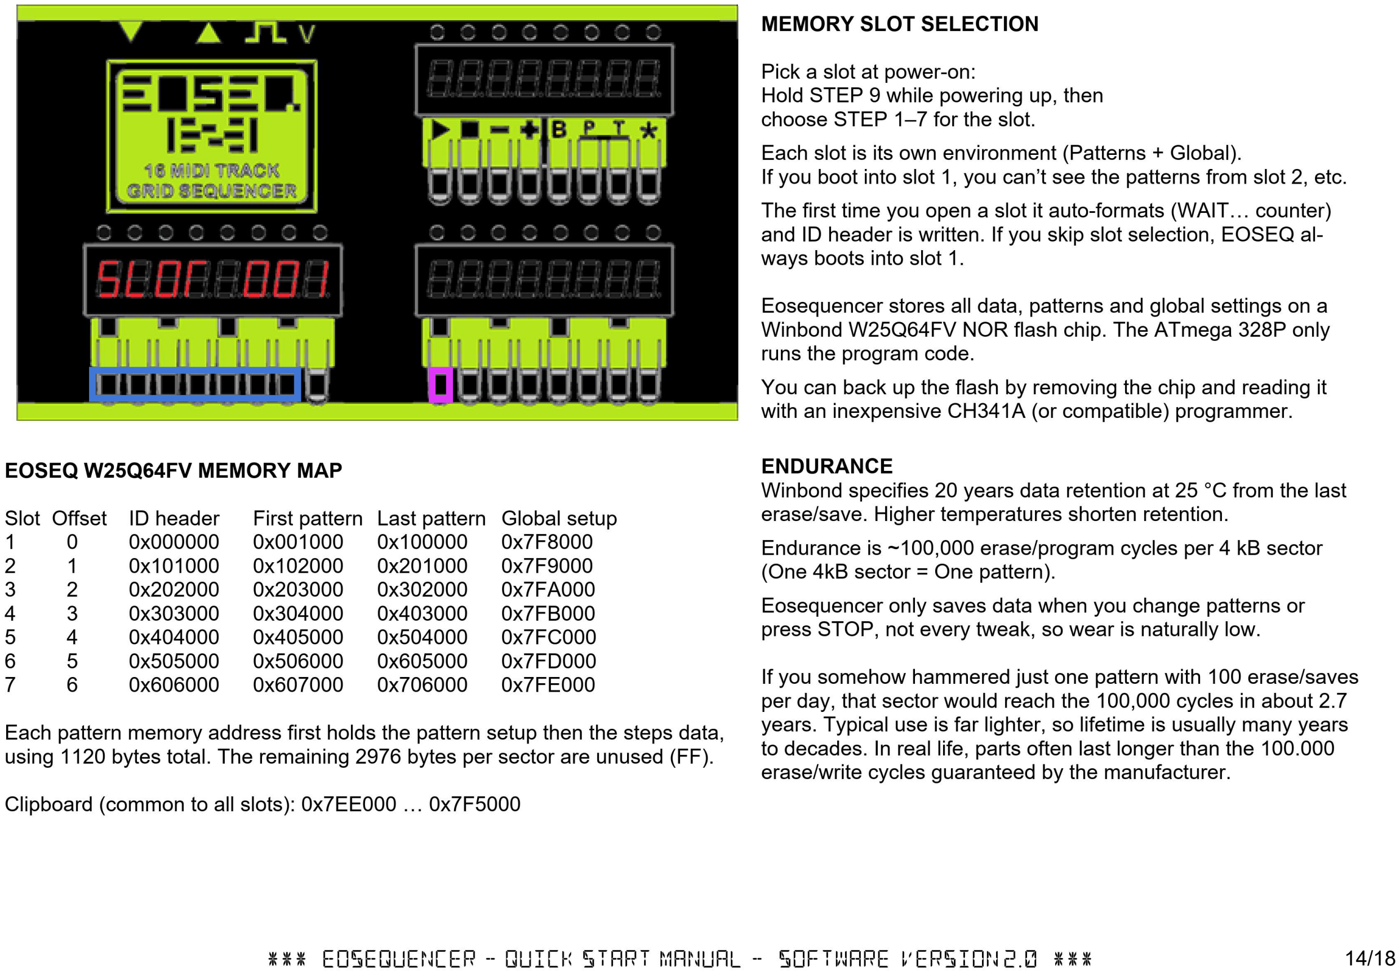
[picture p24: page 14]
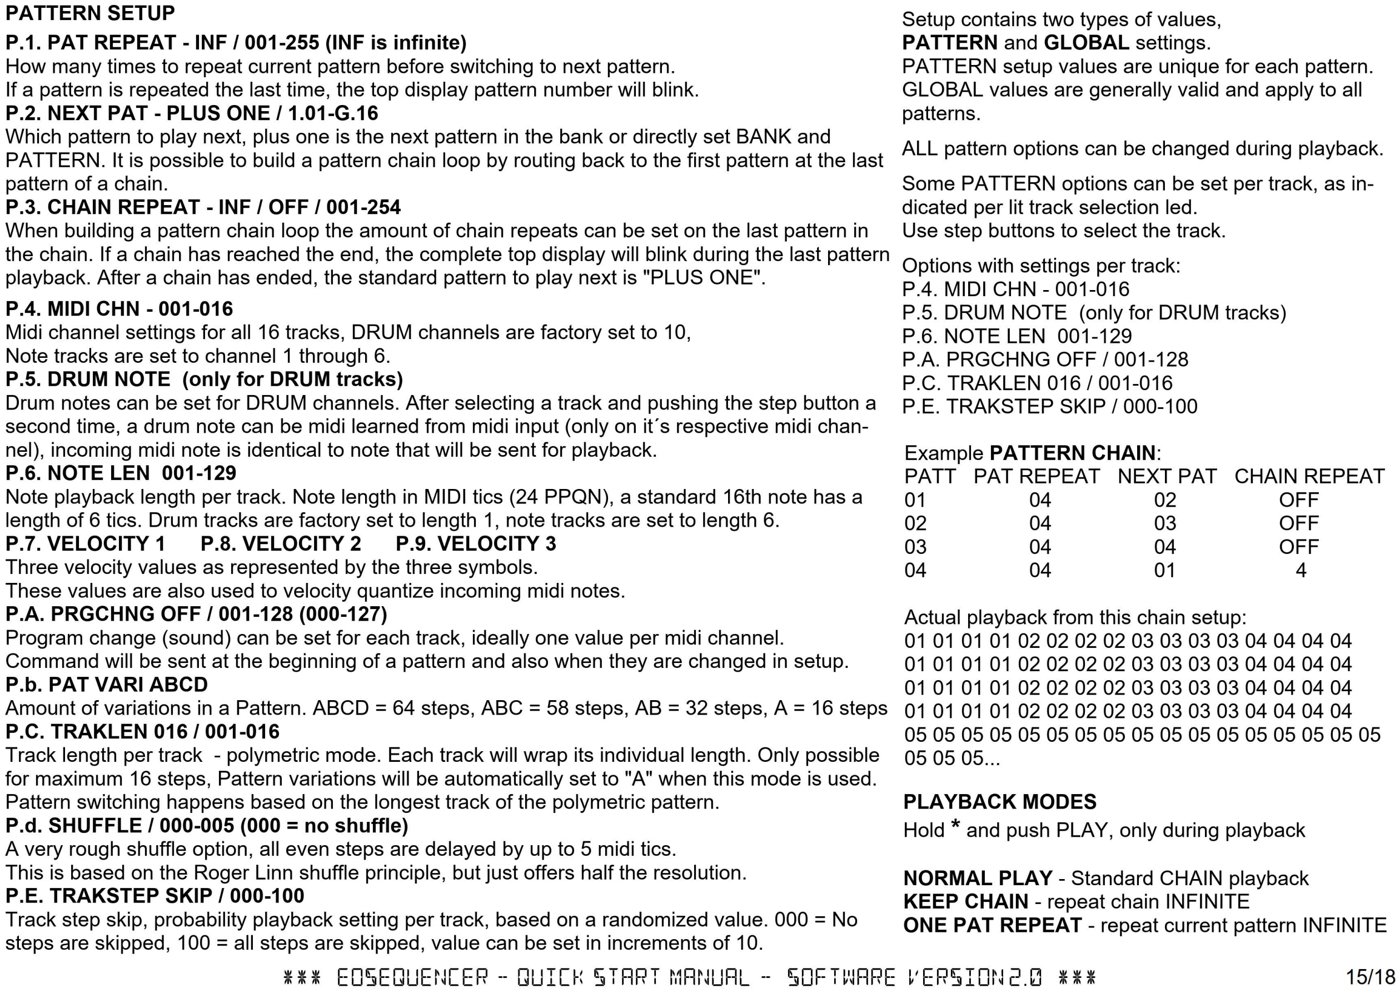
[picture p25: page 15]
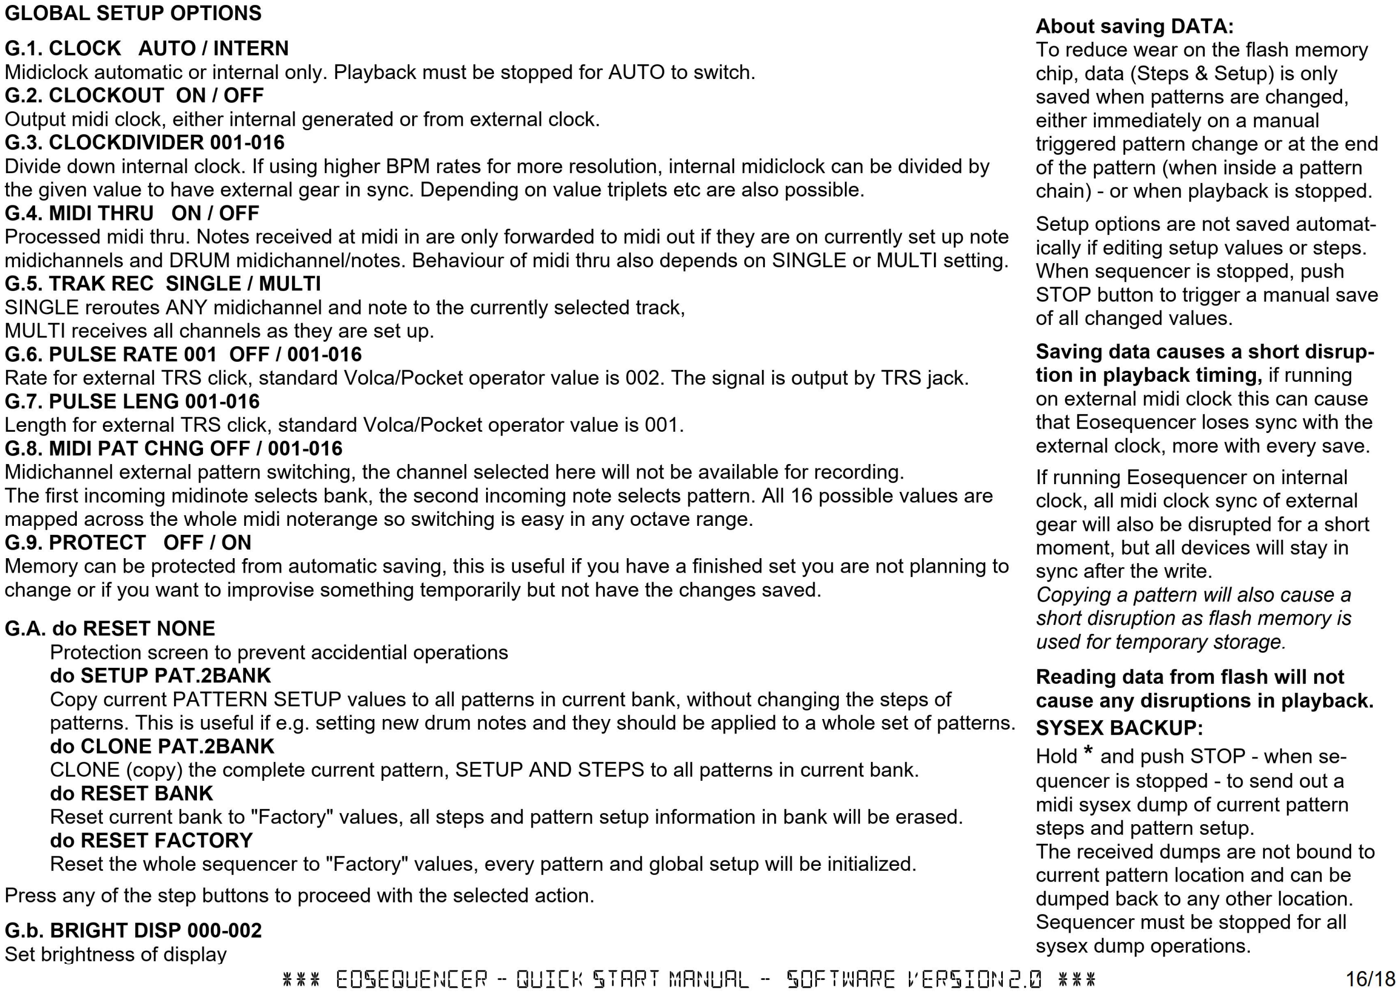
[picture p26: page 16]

Can I connect the sequencer to a DAW or is it only for standalone use?
Yes, it can be connected to a DAW, but your computer must have a 5 pin DIN MIDI interface. What kind of power supply do I need to run the sequencer?
In either of the two build versions (9V or 5V DC), Eosequencer typically requires 500 mA.
If running from a power bank, you can extend runtime by reducing the brightness.
Do I need to stop the sequencer to change setup values?
Almost all values can be changed during playback. Only the following require the sequencer to be stopped: SETUP PAT.2BANK, CLONE PAT.2BANK, RESET BANK, and RESET FACTORY. If you find pattern chain editing too cumbersome, you can also do it during playback in Setup. First set P.2. NEXT PAT, then set P.1. PAT REPEAT to chain patterns easily without much menu switching. Audio and MIDI Troubleshooting
I can't hear any sound from my instrument. What could be wrong?
Always check if the track is muted. Note that the segment dot playback indicators will not show muted tracks.
I can't hear or record anything from the keyboard connected to MIDI IN. What should I check?
MIDI THRU must be enabled and properly configured. If you are recording in MULTI mode and play note 38 on channel 10, there must be a drum track assigned to channel 10, note 38 otherwise it won’t play. Also, only channels 1 to 6 are passed through in the default setting. If you play on channel 7, it won’t be heard. In SINGLE mode, any MIDI channel and note will play, but only on the currently selected track.
My drum sounds are getting cut off. Why is this happening?
The default note length for drum tracks is 1, which works well for synth modules but can truncate samples on a sampler. Increase the note length for longer playback. You can use the SETUP PAT.2BANK function to apply the updated setting to the whole bank.
How does the built-in General MIDI synth work?
The internal synth is based on a SAM2695 GM chip, which outputs only to its internal speaker in the standard configuration. Sounds can be changed with Program Change messages. Channel 10 offers a few drum sounds, while all other channels provide a full GM sound set. Playback volume can be set by changing velocity values. See the SAM2695 datasheet for a complete instrument list.
I edit steps, but they are not being played back. What might be the issue?
Make sure Mirror mode is enabled when editing (all four ABCD LEDs lit). If Mirror is off, your steps are only recorded into the currently selected variation.
When I press a step button in Mirror mode, nothing shows up. Why does the step not appear?
If the step is active in another variation but not in the one currently shown, the first press will remove it from that unseen variation. A second press is needed to add the step in all variations. Mirror mode always displays only the currently playing variation. This doublepush mechanism is intentional and ensures clean variation handling.

## *** FREQUENTLY ASKED QUESTIONS * PART 1 ***

What happens when I change the playback mode during a repeated pattern or chain?
If you switch to KEEP CHAIN or ONE PAT REPEAT, the current chain or pattern will loop indefinitely. This allows for extended jamming even if a part was originally set to repeat only e.g. 16 times. The blinking character display during the last repeat helps you decide when to extend. NORMAL PLAY will follow the programmed setup values (PAT REPEAT, NEXT PAT, CHAIN REPEAT). Switching back to NORMAL PLAY resets all repeat counters, which may not be desirable in all cases. To exit an looped chain cleanly, switch to a pattern outside the loop or the next prepared pattern chain.
What happens when I use shuffle together with polymeter?
Polymetric tracks loop independently, but shuffle always applies to steps 2, 4, 6, etc., based on a full 16-step grid.
Why does the step nudge feature behave strangely when polymeter is active?
Step nudging always shifts all 16 steps, regardless of polymeter settings. This is a performance feature, allowing you to shift steps in and out of the active playback area set by track length.
I copied a pattern, but after powering off and on, it's gone. Why wasn’t it saved?
There are 8 slots for copy/paste. Each time you copy a pattern, the slot advances to reduce flash wear. If you want a specific pattern to persist after power-off, you need to copy it 9 times. However, if you copy/paste patterns frequently, the clipboard will eventually be overwritten.
Playback stutters when I copy a pattern. What causes this?
This is due to flash memory writes. Because of limited RAM, it's not possible to copy a pattern to flash without some CPU impact, which may cause momentary stuttering, similar to saving data when changing patterns.
What is a SysEx dump and how is it used?
A SysEx (System Exclusive) dump is a block of MIDI data used to store or recall sequencer settings and patterns. An Eosequencer pattern dump is around 2 kilobytes and includes all pattern steps and setup data - not global data. You can use tools like Bome's SendSX or any standard MIDI monitor to send/receive dumps. The sequencer must be stopped during SysEx transfers. If the Protect setting is enabled in Setup, dumps cannot be received.
There is a gap at the beginning of the pattern when I send a program change. Why does this happen?
Some grooveboxes and synths take time to respond to a Program Change message. EOSequencer sends the Program Change just before playback starts or just before the first note of a pattern. Depending on the receiving device, this may cause a delay or missed note.
I made a mistake while recording a take. How can I retry without erasing the entire pattern?
The best workflow is to prepare all MIDI channels as needed, and then lay down a basic click track or beat on drum tracks. Before recording, copy the pattern to the clipboard. If the take fails, immediately paste the backup pattern and try again, no need to stop playback. Once satisfied, copy the new version and continue layering.

## *** FREQUENTLY ASKED QUESTIONS * PART 2 ***

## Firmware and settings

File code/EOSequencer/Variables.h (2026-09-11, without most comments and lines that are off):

#define DEFAULT_NOTE 36     // Default note when adding steps to a new pattern, else the last used note number is carried on.
#define DEFAULT_MIDI_CH 10  // MIDI Default Channel for all 10 drum tracks - track 1 - 10
#define BUFFER_SIZE 64      // UART software buffer size, can go as low as 64
#define SERIAL_RX_BUFFER_SIZE 64
#define MIDI_OVER_USB 0  // When set will use 38400 bauds for the Serial interface - EOSequencer will not be recognized as a midi device, needs special COM drivers to use it via USB with a DAW.
#define DRUM_TRACKS 10  // This can't go above 16 - not recommended to change
#define NOTE_TRACKS 6   // This can't go above 8 - not recommended to change
#define PATTERNS 16     // This can't go above 64 - not recommended to change
#define PT_BANKS 16     // # of Pattern Banks - not recommended to change
#define STEPS 16        // This can't go above 16 - not recommended to change
#define TEMPORARY_MESSAGE_TIME 100           //Time for error messages and playback mode splashscreen
#define EXTERNAL_CLOCK_TIMER (F_CPU / 2560)  // Since a midi byte is 10 bits, 2560 is the 100% correct divider
#define MIDI_INPUT_BUFFER (18)               // (4 * 2) - The size of the internal buffer used for recording, do not change
#define FLASH_CHIPSIZE MB64
#define FLASH_VERSION '2'
enum {
  kButtonNone = 0,
  kButtonClicked,
  kButtonHold,
  kButtonRelease,
  kButtonReleaseNothingClicked,
  kRightSteps = 0,
  kRightTrackSelection,
  kRightPatternSelection,
  kRightMenuCopyPaste,
  kRightMenu,
  kMuteMenu,
  midiNoteOn = 0x90,
  midiNoteOff = 0x80,
  midiProgramChange = 0xC0,
  midiChannels = 16,
  menuFirst = 0,
  menuPtPlays = 0,
  menuPtNext,
  menuPtPlaysChain,
  menuMIDIChannel,
  menuNote,
  menuNoteLen,
  menuAccent1,
  menuAccent2,
  menuAccent3,
  menuProgramChange,
  menuVariationsABCD,
  menuTrackLen,
  menuShuffle,
  menuTrackProbability,
  menuClockType,
  menuSyncOut,
  menuClockDivider,
  menuMidiThru,
  menuMultitrack,
  menuPulseOut,
  menuPulseOutLen,
  menuMIDIinPattern,
  menuProtect,
  menuInit,
  menuBrightness,
  lastMenu = menuBrightness,
  kLeftMain = 0,
  kRandom,
  kErase,
  kMemoryProtectMessage = 0,
  kPatternRepeatMessage,
  kRepeatModeNormal = 0,
  kRepeatModeChain,
  kRepeatModePattern,
  kSysexDump,
  kStopSequencer
};
SPIFlash flash;
byte segments[3][8];
byte leds[3];
byte buttons[3];  // raw button values
byte buttonEvent[3][8];
byte buttonEventWasHolding[3] = { 0, 0, 0 };
byte buttonIsHolding[8];
volatile byte buttonDownTime[3][8];  // time of button press
volatile byte variation = 0;         // ABCD Variations
volatile char forceVariation = -1;
byte curTrack = 0;
byte curLeftScreen = 0;   //main interface
byte curRightScreen = 0;  //step interface
byte currentPattern = 0;
byte nextPattern = 0;
byte currentPatternBank = 0;
byte nextPatternBank = 0;
uint16_t patternBitsSelector;
volatile bool mirror = false;
bool somethingClicked = false;
bool somethingHappened = false;  // a button press was registered
bool forceAccent = false;
volatile bool seqPlaying = false;
volatile byte seqPosition = 0;
volatile byte PPQcounter = 0;
bool somethingChangedPattern = false;  // if true saves the pattern (steps, double steps variations...)
bool somethingChangedGlobal = false;   // if true saves global parameters (clock int/ext, sync out, write protect...)
volatile bool streamNextPattern = false;
volatile bool loadPatternNow = false;
byte ignoreButtons = false;
byte lastVelocity = B00000011;
byte lastVelocityMIDI = B00000011;
bool editingNote = false;
byte editStep = 0;
byte editVariation = 0;
byte prevPlayedNote[NOTE_TRACKS];  //
byte menuPosition = 0;
byte initMode = 0;
char flashHeader[8];
uint16_t prevMuteTrack = 0;
byte totalFlashErrors = 0;
byte prevPatternTotalVariations = 4;
volatile byte midiInputStage = 0;
volatile byte midiInputBuffer[2] = { 0, 0 };  // buffer for analyzing current midi input
byte midiOutputBuffer[3][48];                 //144 bytes - 48 3byte midi events
volatile byte midiOutputBufferPosition = 0;
volatile byte calculateSequencer = 0;
uint16_t patternPagePos = 0;
uint16_t pagePos = 0;
char editingNoteTranspose = -127;
bool noteTransposeWasChanged = false;
bool noteTransposeEditAllSteps = false;
byte leftLEDsVarSeq = 0;
byte leftLEDsVarSeqBuffer = 0;
uint16_t chaseLEDs[2] = { 0, 0 };
uint16_t chaseLEDsBuffer[2] = { 0, 0 };
byte stepVelocity = 0;
byte drumStepLastVelocity = B00000011;
byte noteStepGlideDoubleOff = 0;
bool ignoreNextButton = false;
volatile byte currentPlaysPattern = 0;
volatile byte currentPlaysChain = 0;
byte repeatMode = 0;
byte showTemporaryMessage = 0;
byte temporaryMessageCounter = 0;
byte xm = 0;
byte inputByte = 0;
volatile byte noteLenCounters[DRUM_TRACKS + NOTE_TRACKS];
volatile byte noteLenCountersLED[DRUM_TRACKS + NOTE_TRACKS];
volatile byte tickOutCounter = 0;
volatile byte tickOutCounterLen = 0;
volatile bool tickOutPinState = false;
bool recordEnabled = false;
byte recordBuffer[3][MIDI_INPUT_BUFFER];  //= one full midi event like note on
volatile byte recordBufferPosition = 0;
bool isSelectingBank = false;
byte preventABCD = 0;  //flag for preventing ABCD mode change when button [0][7] is pushed
uint16_t realBPM = 120;
uint8_t quantizedValue = 0;  // Global quantized timer value (0-15) for char animation counter
byte trackPosition[DRUM_TRACKS + NOTE_TRACKS] = {};
const byte trackSequence[16] = { 9, 8, 7, 6, 15, 5, 14, 4, 13, 3, 12, 2, 11, 1, 10, 0 };  // playback priority of tracks, reverse order! 0 is drum track 1, 10 is note track 1
volatile byte longestTRACK = 0;                                                           // amount of steps in longest track, polymetrics
volatile byte longestTrackIndex = 0;                                                      //for polymetrics, to determine when to switch to next pattern, index is pointing to patternData.trackLength
bool doAlign = false;                                                                     //alignment of polymetric tracks
volatile uint16_t muteTrack = 0x00;                                                       //all channels unmuted;
volatile byte shuffleCounter = 0;                                                         //each even 16th and 32nd step is generated by shufflecounter and value in setup
volatile bool alignedToPlay16 = false;                                                    //shuffled or straight playback flag for 16th step
volatile bool alignedToPlay32 = false;                                                    //same for 32nd step
volatile bool isEvenStep = false;                                                         //flag to determine even steps when to start shuffle counter
volatile byte ledPosition = 0;                                                            //position memory to show shuffle correctly on playback leds
volatile byte midiClockCounter = 0;                                                       // Counter for midiclock divide down division
volatile bool midiToBank = true;                                                          // Flag to interpret first midi note on external pattern switching control as bank number (second as patttern)
volatile bool sysexActive = false;
volatile bool receivingSysEx = false;
volatile uint16_t byteIndex = 0;
volatile uint8_t tempByte = 0;
volatile bool highNibble = false;
volatile uint8_t syxinputByte;
volatile bool startup = true;
volatile bool midiPanic = false;
const byte pwmBrightness[] = {
  0b10001000,  // 1/16 brightness
  0b10001001,  // 2/16 brightness
  0b10001010,  // 4/16 brightness
  0b10001011,  // 10/16 brightness
};
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

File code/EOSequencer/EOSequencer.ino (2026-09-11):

/*
 * EOSequencer — fork of Beat707NXT
 *
 * Copyright (c) 2018–2025 Gert Borovcak
 * Original Beat707 portions Copyright (c) 2011–2018 William Kalfelz (Beat707 / Wusik.com)
 *
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
 * SPDX-License-Identifier: GPL-3.0-or-later
 * Project: https://www.eoseq.com
 * Support William: https://ko-fi.com/williamkalfelz  •  https://www.patreon.com/williamkwusik
 */

#include "Lib_Flash.h"
#include "Functions.h"
#include "Variables.h"
#include <util/atomic.h>

void setup() {
  DDRC = 0xFF;  // For the Pulse-Out (analog pins, A54 Header)
  pulseOut(false);
  realBPM = 120;  //the BPM set at startup
  
  startMIDIinterface();
  initTM1638();
  reset();
  resetPatternBank();  //sets back all steps to init
  patternData.init();
  globalData.init();
  //splashScreen();  //removed to save memory

  readButtons();
  masterOffset = 0;

  if (buttons[2] & _BV(0)) {
    for (;;) {
      readButtons();

      if (buttons[1] & _BV(6)) masterOffset = 6;
      else if (buttons[1] & _BV(5)) masterOffset = 5;
      else if (buttons[1] & _BV(4)) masterOffset = 4;
      else if (buttons[1] & _BV(3)) masterOffset = 3;
      else if (buttons[1] & _BV(2)) masterOffset = 2;
      else if (buttons[1] & _BV(1)) masterOffset = 1;
      else if (buttons[1] & _BV(0)) masterOffset = 0;

      segments[1][0] = S_S;
      segments[1][1] = S_L;
      segments[1][2] = S_O;
      segments[1][3] = S_T;
      printNumber(1, 5, masterOffset + 1);
      sendScreen();

      // keep halting while ANY of these are held
      if (!(buttons[2] & _BV(0))) break;

      _delay_ms(10);
    }
  }
  //sendScreen();
  waitMs(800);

  buttons[0] = buttons[1] = buttons[2] = 0;

  flashInit(false);
  loadPatternBank(0);

  calculateSequencer++;
  startup = false;
  setupTimerForExternalMIDISync(!midiClockInternal);
}

void loop() {


  if (sysexActive) {
    handleSYSEXInput();
  } else {  // Only run these sections when sysex is not active

    if (dumpReceived) {
      ShowTemporaryMessage(kSysexDump);
      dumpReceived = false;
    }

    if (!midiClockInternal) {
      doTickSequencer();  //
    }

    checkPatternStream();

    unsigned long currentTime = millis();
    unsigned long frameDuration = currentTime - previousFrameTime;
    previousFrameTime = currentTime;

    accumulatedInterfaceTime += frameDuration;
    accumulatedInterfaceTimeAlltime += frameDuration;

    if (accumulatedInterfaceTimeAlltime >= 400) {  //400mS throughput check
      eventsPrevious = eventsSent / 10;
      eventsSent = accumulatedInterfaceTimeAlltime = 0;
    }

    // Check interface if enough time has passed
    const byte interfaceCheckThreshold = 12;  // 12mS

    if (accumulatedInterfaceTime >= interfaceCheckThreshold) {
      readButtons();
    }

    if (midiClockInternal) {
      handleMIDIInput();
      if (sysexActive) return;
    }

    if (accumulatedInterfaceTime >= interfaceCheckThreshold) {
      checkInterface();
      accumulatedInterfaceTime = 0;
    }

    // Frame skip logic
    static uint8_t framePattern[6];

    static const uint8_t pattern_111111[6] = { 1, 1, 1, 1, 1, 1 };
    static const uint8_t pattern_111110[6] = { 1, 1, 1, 0, 1, 1 };
    static const uint8_t pattern_111100[6] = { 1, 1, 0, 0, 1, 1 };
    static const uint8_t pattern_110100[6] = { 1, 1, 0, 0, 0, 1 };
    static const uint8_t pattern_100100[6] = { 1, 0, 0, 0, 0, 1 };
    static const uint8_t pattern_100000[6] = { 1, 0, 0, 0, 0, 0 };

    const uint8_t* patternEvents;
    const uint8_t* patternBPM;

    // Choose pattern based on event load
    if (eventsPrevious <= 0x05) {
      patternEvents = pattern_111111;
      visualPattern = B00000000;
    } else if (eventsPrevious <= 0x20) {
      patternEvents = pattern_111111;
      visualPattern = B00001000;
    } else if (eventsPrevious <= 0x2D) {
      patternEvents = pattern_111110;
      visualPattern = B00001000;
    } else if (eventsPrevious <= 0x3A) {
      patternEvents = pattern_111100;
      visualPattern = B01001000;
    } else if (eventsPrevious <= 0x47) {
      patternEvents = pattern_110100;
      visualPattern = B01001000;
    } else if (eventsPrevious <= 0x54) {
      patternEvents = pattern_100100;
      visualPattern = B01001000;
    } else {
      patternEvents = pattern_100000;
      visualPattern = B01001001;
    }

    // Choose pattern based on BPM (high BPM = reduce frames)
    if (realBPM < 200) {
      patternBPM = pattern_111111;
    } else if (realBPM < 300) {
      patternBPM = pattern_111110;
    } else if (realBPM < 400) {
      patternBPM = pattern_111100;
    } else if (realBPM < 500) {
      patternBPM = pattern_110100;
    } else if (realBPM < 800) {
      patternBPM = pattern_100100;
    } else {
      patternBPM = pattern_100000;
    }

    // Final pattern = pattern with most zeroes
    for (byte i = 0; i < 6; i++) {
      framePattern[i] = patternEvents[i] && patternBPM[i];
    }

    // Screen update check
    if (screenUpdate) {
      screenUpdate = false;

      if (framePattern[(PPQcounter + 5) % 6]) {
        createScreen();
        sendScreen();
      }
    }

    if (editingNoteTranspose != -127 && stepBeenHold() == -2) {
      editingNoteTranspose = -127;
    }

    // Animation timer, not synced to BPM
    const unsigned long animationCycleTime = 6000;  // 6 seconds
    const byte animationSteps = 16;

    unsigned long ms = millis() % animationCycleTime;
    quantizedValue = ms / (animationCycleTime / animationSteps);
    //}
  }
}
//END OF LINE

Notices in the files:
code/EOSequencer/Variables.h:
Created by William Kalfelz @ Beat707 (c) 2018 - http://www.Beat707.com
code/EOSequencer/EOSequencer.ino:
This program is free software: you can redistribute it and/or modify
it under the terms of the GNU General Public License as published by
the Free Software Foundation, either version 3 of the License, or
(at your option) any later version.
